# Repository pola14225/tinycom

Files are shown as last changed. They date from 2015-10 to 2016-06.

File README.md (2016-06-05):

# TinyCom

A small and low cost modular computer system.

Features:
- dimensions less than 5x5cm
- single, dual or quad core 1GHz CPU
- 512GB or 1GB RAM
- USB, HDMI, WIFI, Bluetooth, SD-card, camera, microphones
- real-time clock with battery, on-board temperature sensor
- **made only from widely available parts**
- **can reliably be assembled at home with DIY tools**

Modules:
- TinyCom-A13
- [TinyCom-A20](#tinycom-a20)
- TinyCom-A64
- TinyCom-USB
- [TinyCom-HDMI](#tinycom-hdmi)
- TinyCom-Pilot

## TinyCom-A20

### Specifications

- Dimensions: 4x4 cm
- CPU: Allwinner A20 (Dual-Core ARM Cortex-A7 @ 1Ghz, 40nm process)
- Memory: 512MB DDR3 SDRAM
- PCB: 4 layers, 6 mil traces, 12 mil vias
- Ports: SD-card, serial, USBx3, HDMI, camera

### Pictures

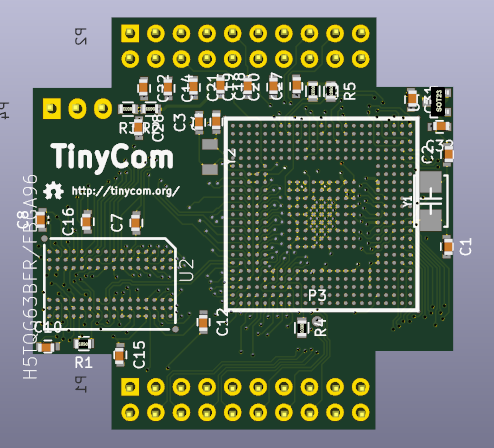
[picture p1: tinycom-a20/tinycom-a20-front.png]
TinyCom-A20 Front


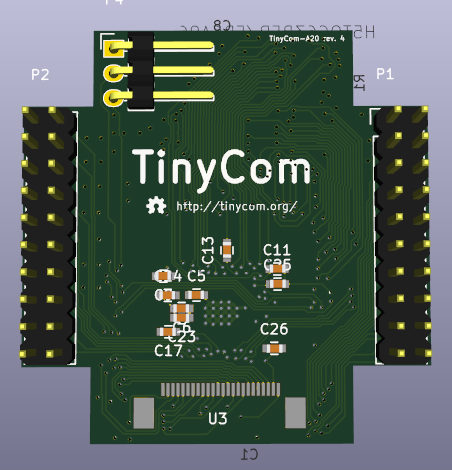
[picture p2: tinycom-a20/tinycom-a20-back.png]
TinyCom-A20 Back


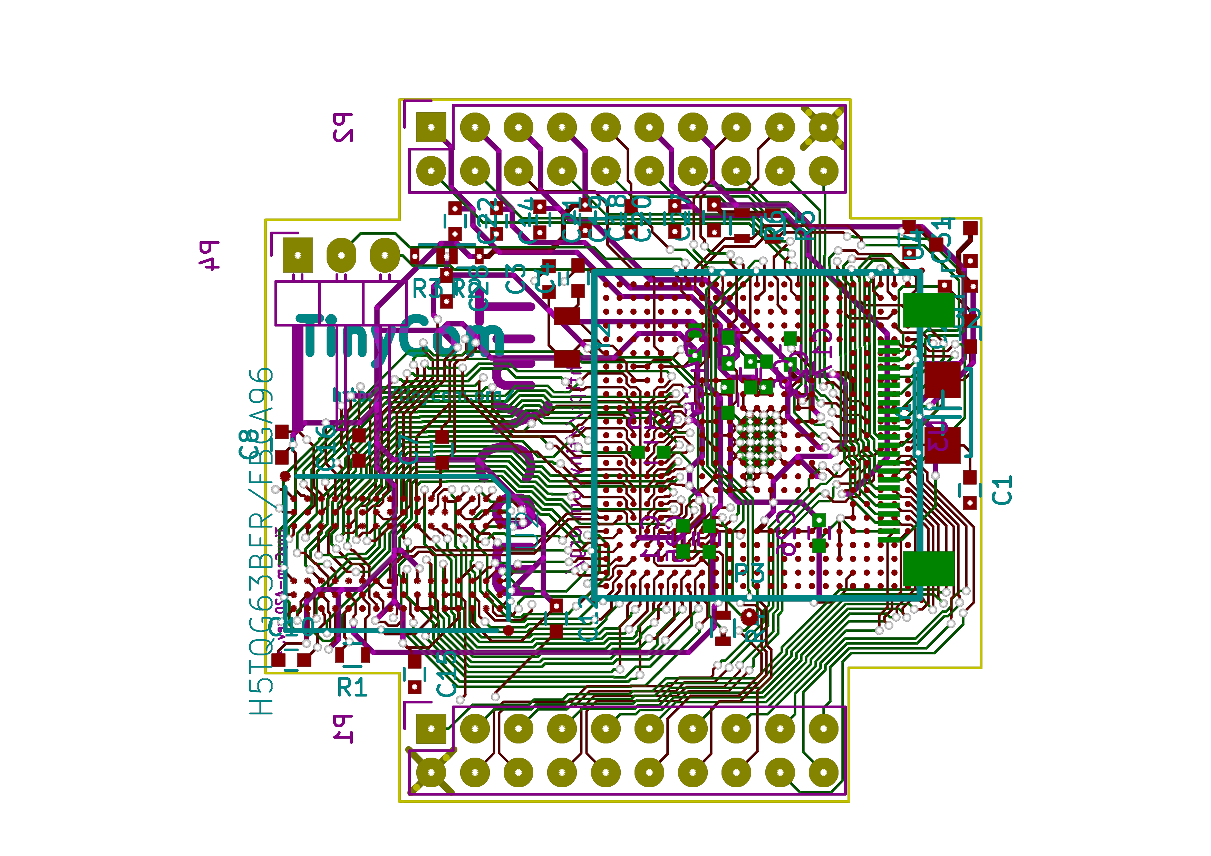
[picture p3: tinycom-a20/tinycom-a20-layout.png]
TinyCom-A20 Layout


## TinyCom-HDMI

- Connectors:  SD-card, USB, HDMI
- Network: WIFI, Bluetooth, ceramic antenna
- 2 microphones
- RTC backup battery
- Board temperature sensor
- PCB: 2 layers

### Pictures

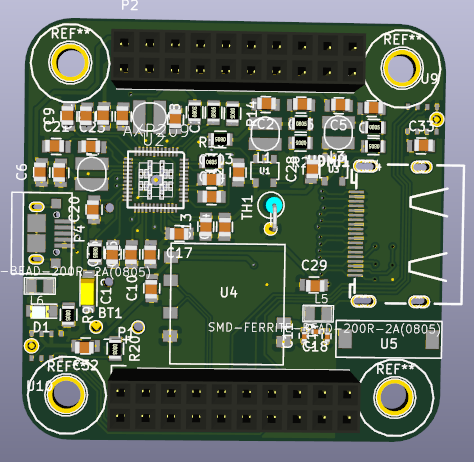
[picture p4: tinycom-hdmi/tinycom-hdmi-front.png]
TinyCom-HDMI Front


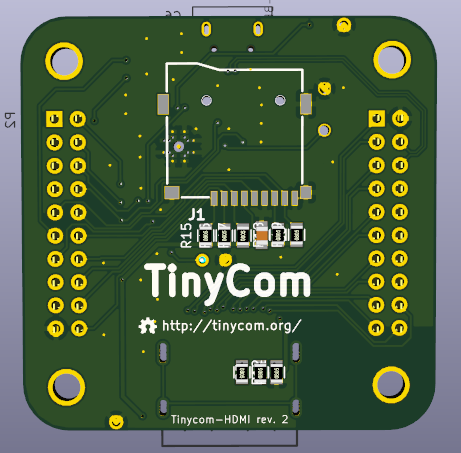
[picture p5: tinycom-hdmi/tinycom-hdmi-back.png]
TinyCom-HDMI Back


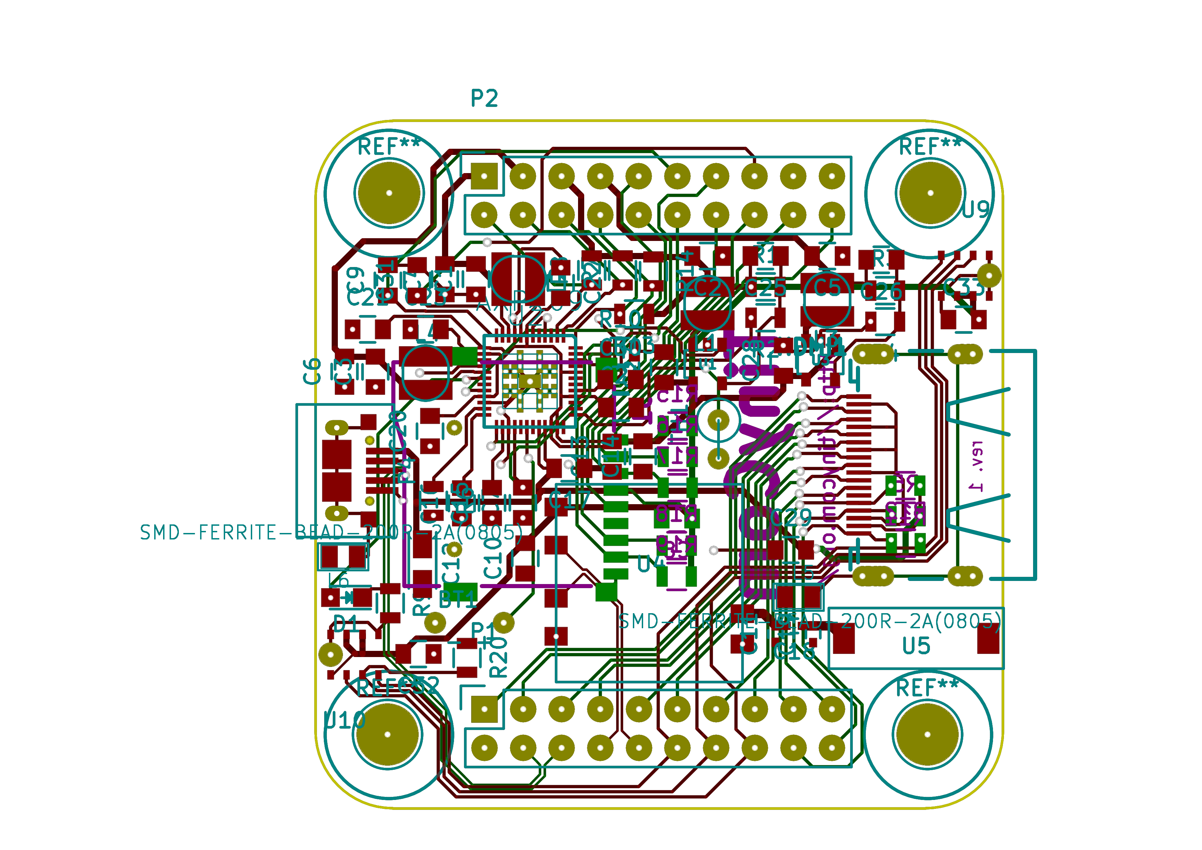
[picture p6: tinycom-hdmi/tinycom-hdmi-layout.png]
TinyCom-HDMI Layout


## Contact

Send email to dj@netforce.com.

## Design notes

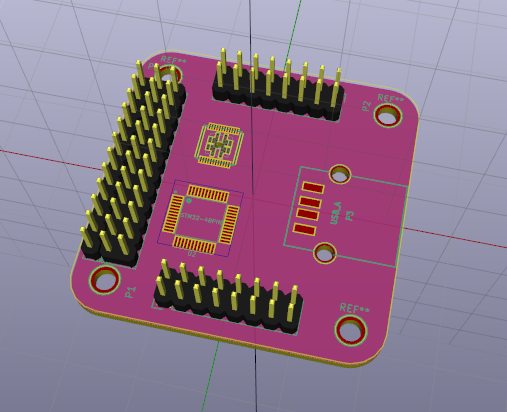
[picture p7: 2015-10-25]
tinycom-pilot/tinycom-pwm-3d.png

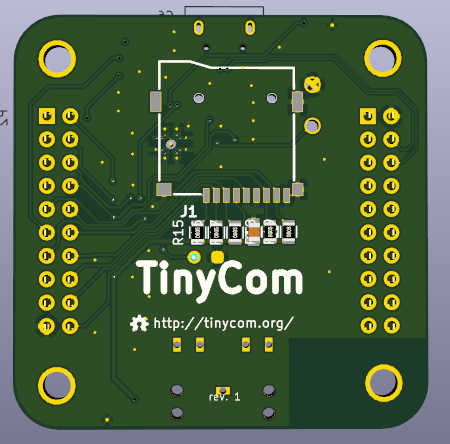
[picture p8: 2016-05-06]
tinycom-audio/tinycom-audio-back.png

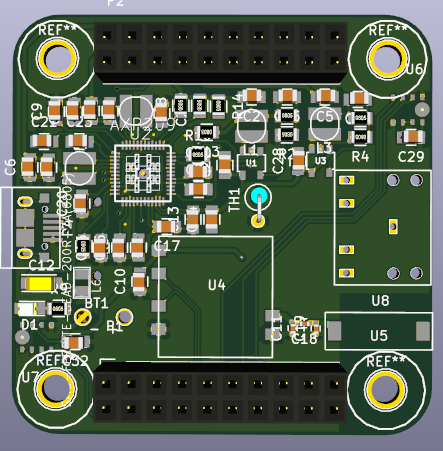
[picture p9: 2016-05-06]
tinycom-audio/tinycom-audio-front.png

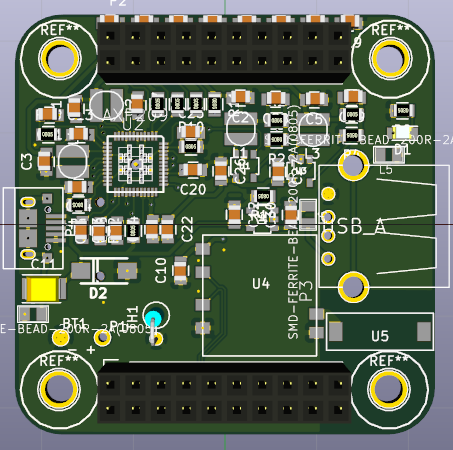
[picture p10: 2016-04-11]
tinycom-usb/tinycom-usb-front.png

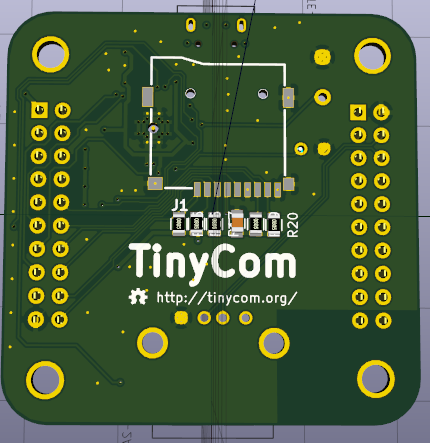
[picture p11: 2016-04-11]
tinycom-usb/tinycom-usb-back.png

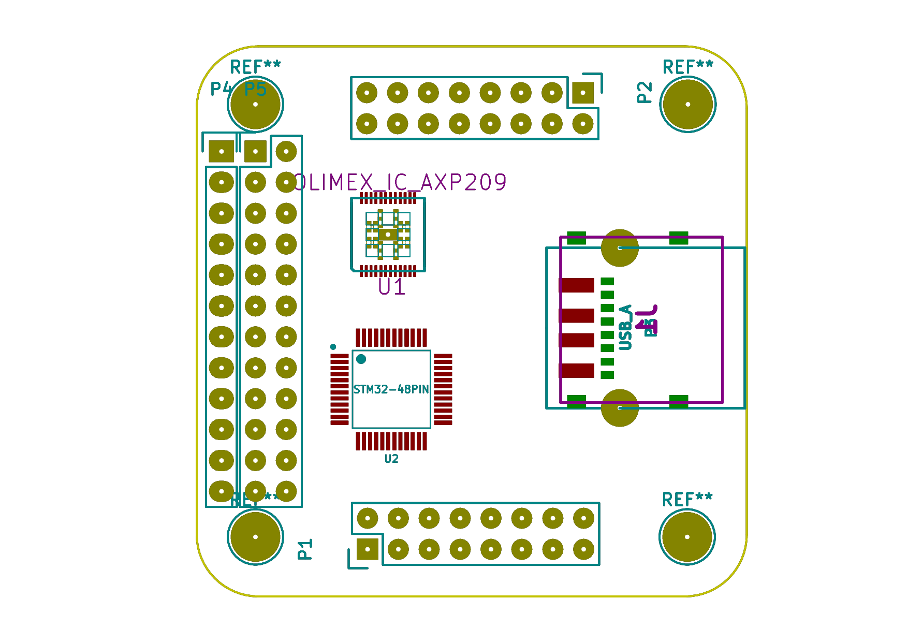
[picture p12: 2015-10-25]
tinycom-pilot/tinycom-pwm-board.png

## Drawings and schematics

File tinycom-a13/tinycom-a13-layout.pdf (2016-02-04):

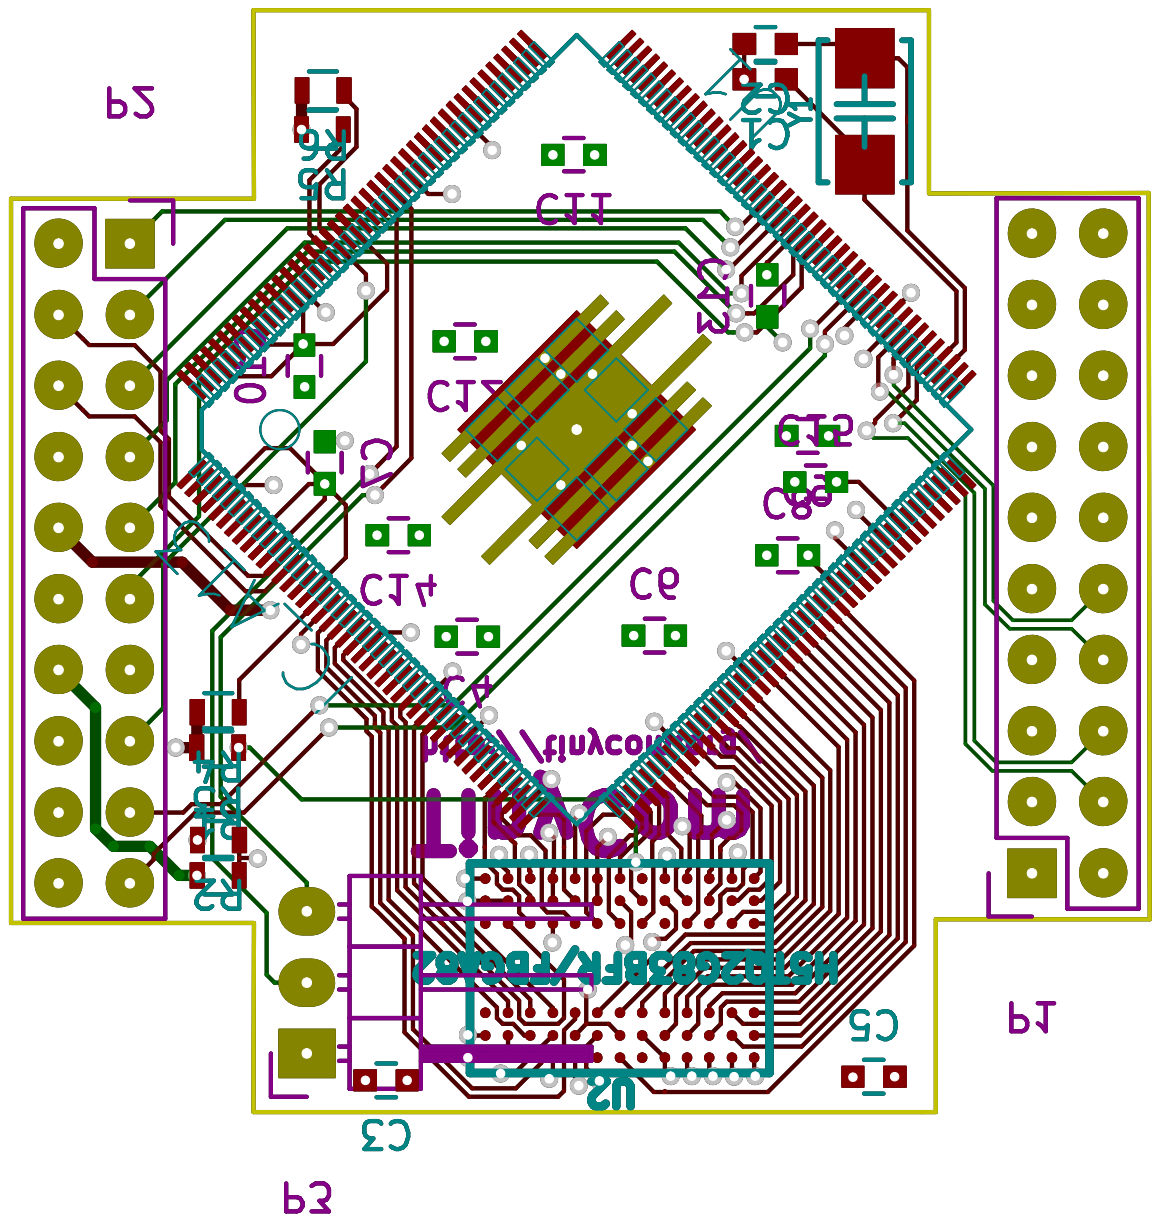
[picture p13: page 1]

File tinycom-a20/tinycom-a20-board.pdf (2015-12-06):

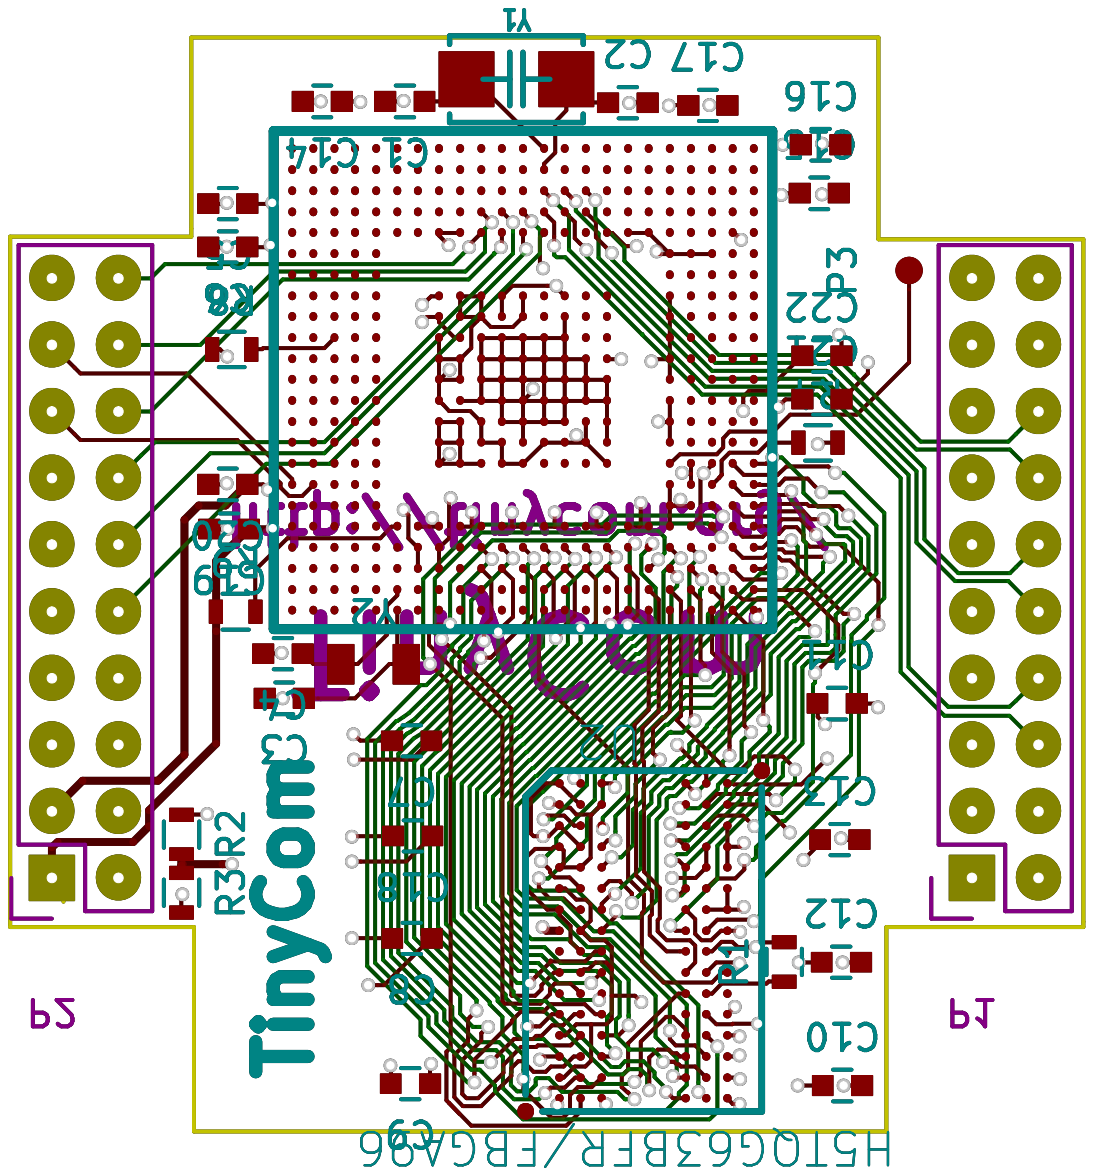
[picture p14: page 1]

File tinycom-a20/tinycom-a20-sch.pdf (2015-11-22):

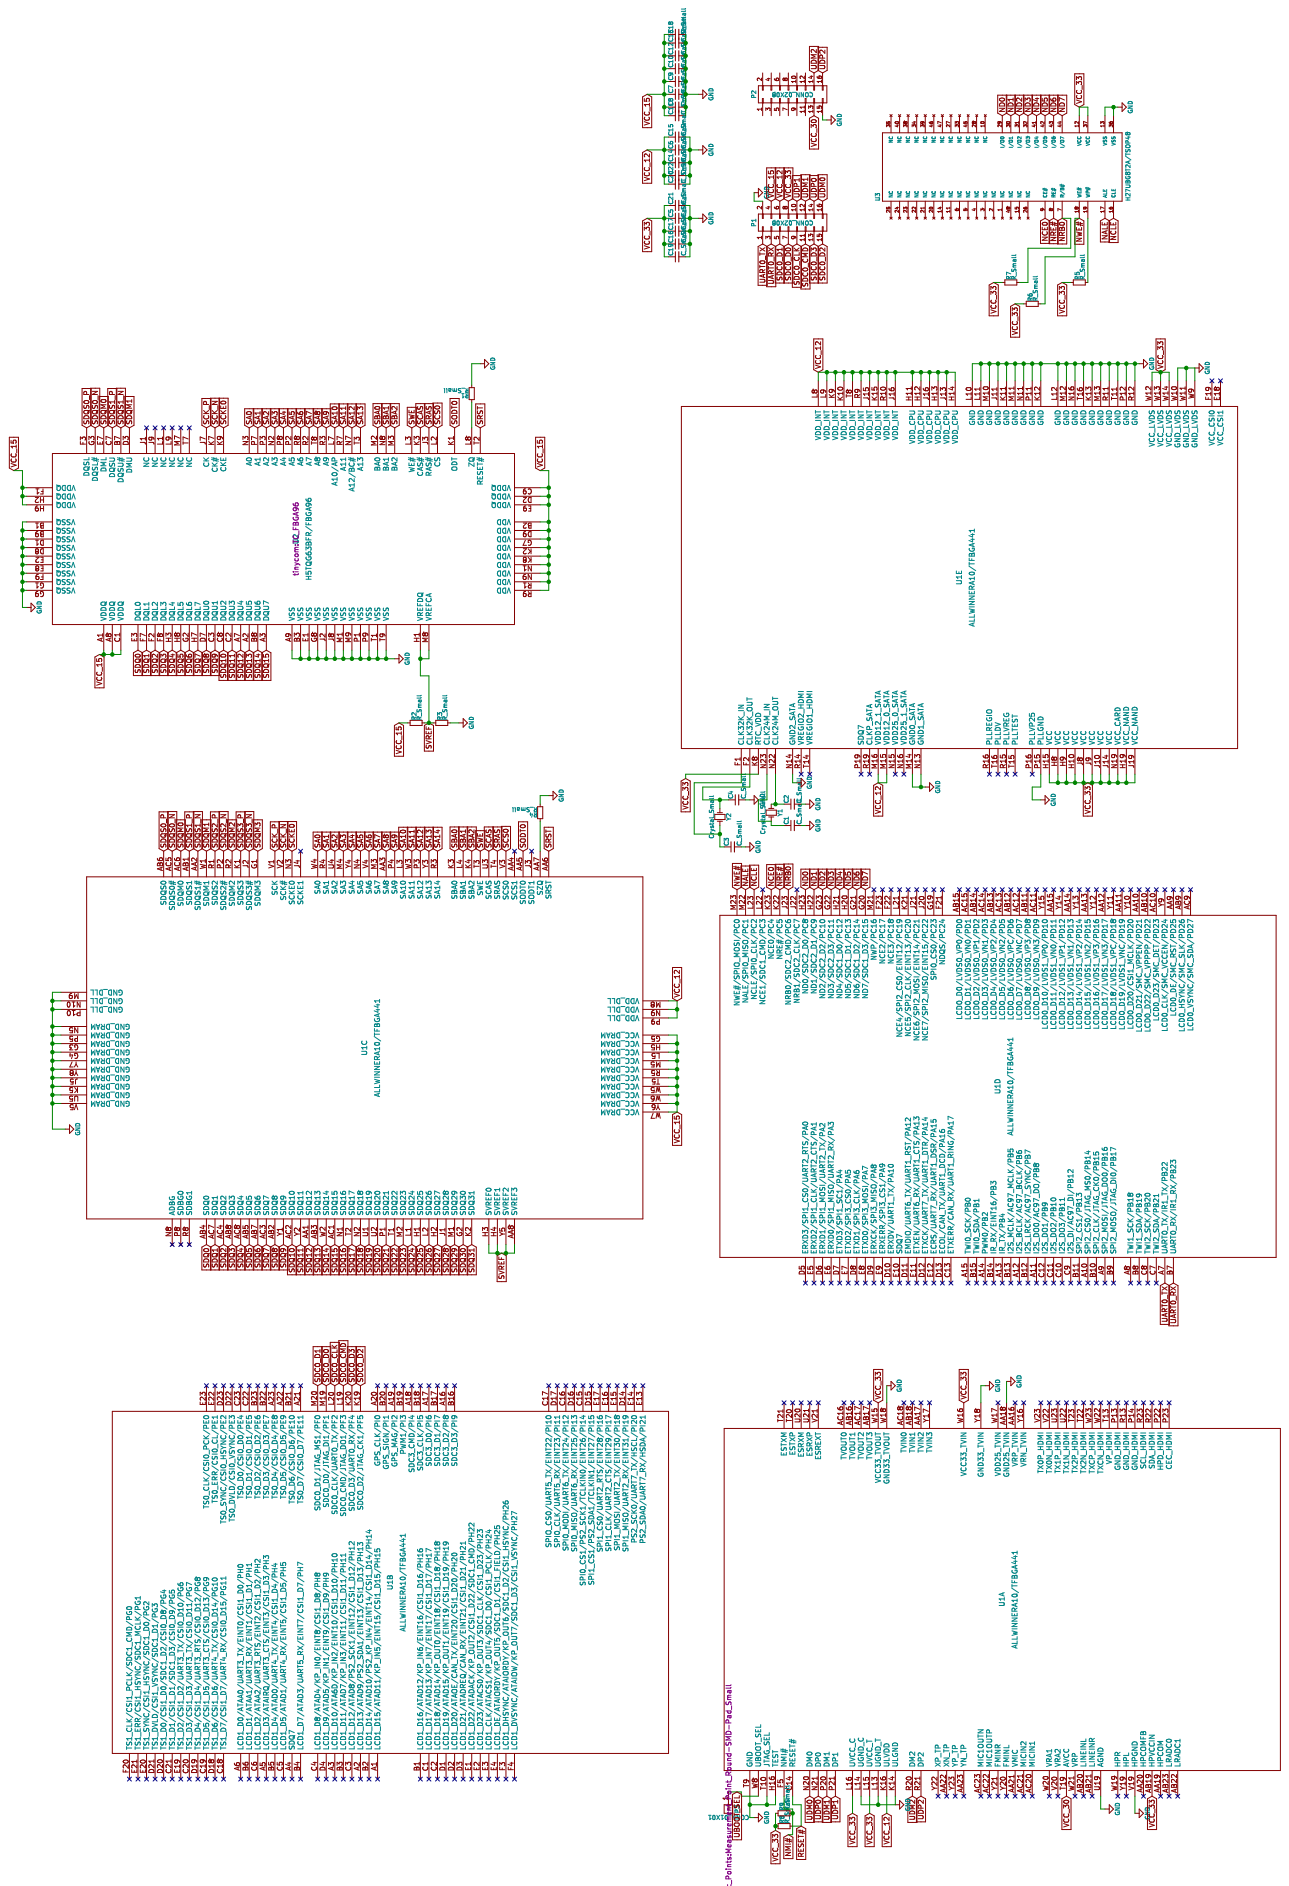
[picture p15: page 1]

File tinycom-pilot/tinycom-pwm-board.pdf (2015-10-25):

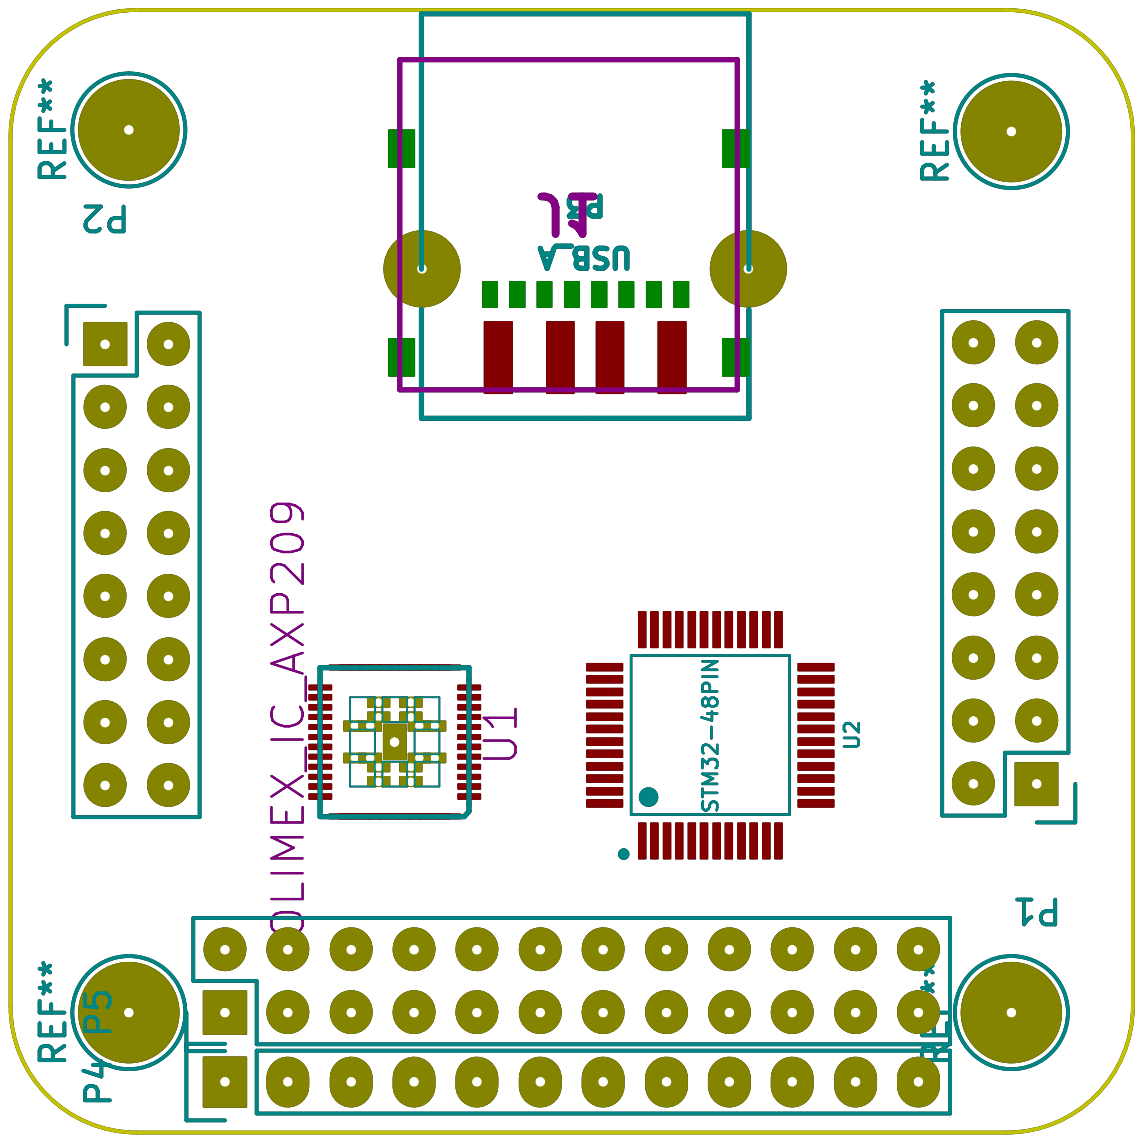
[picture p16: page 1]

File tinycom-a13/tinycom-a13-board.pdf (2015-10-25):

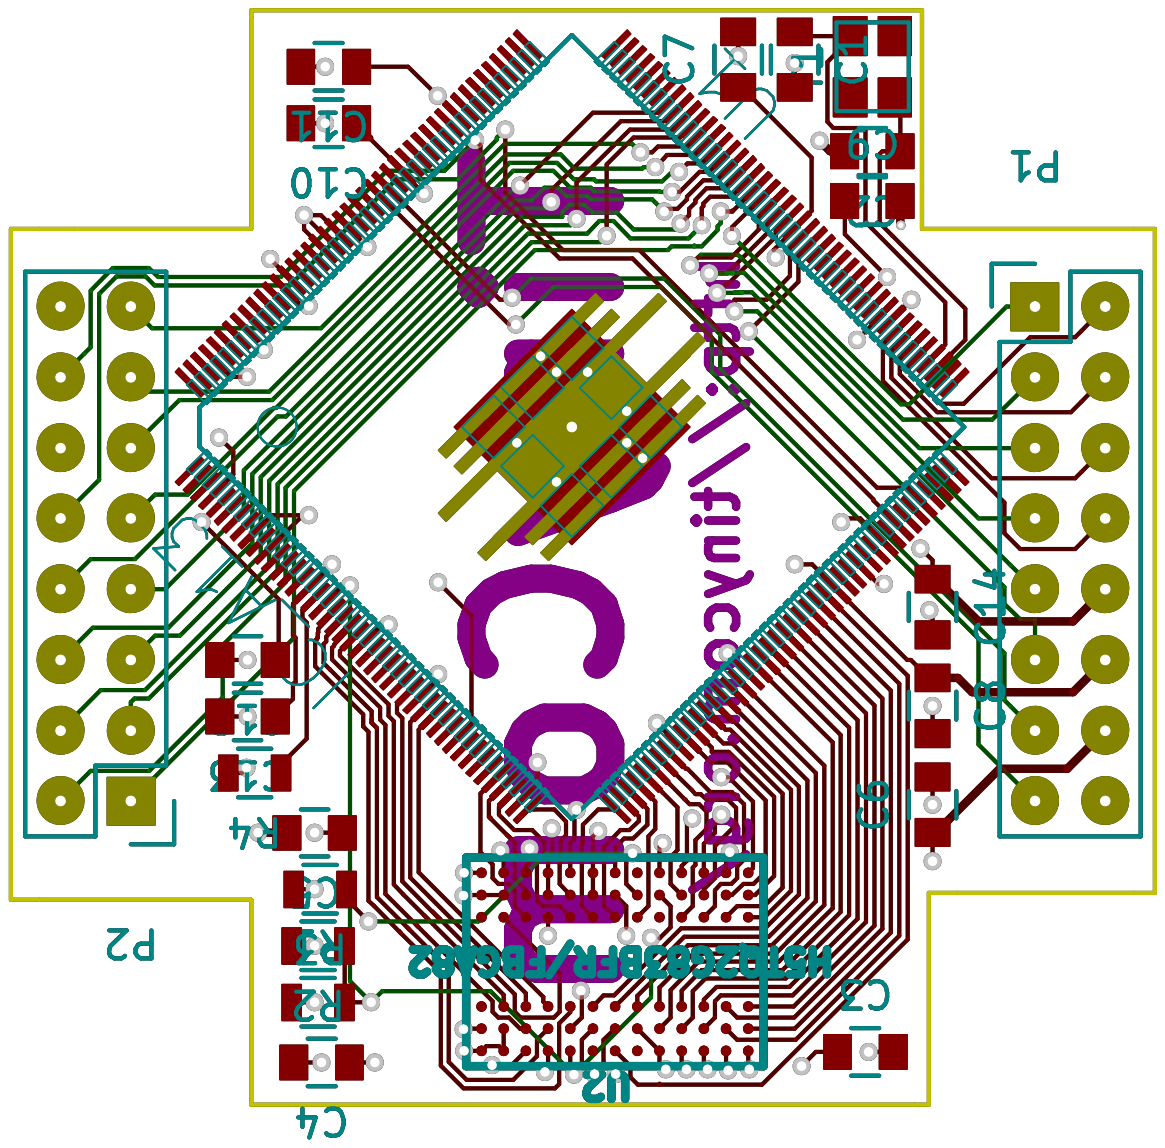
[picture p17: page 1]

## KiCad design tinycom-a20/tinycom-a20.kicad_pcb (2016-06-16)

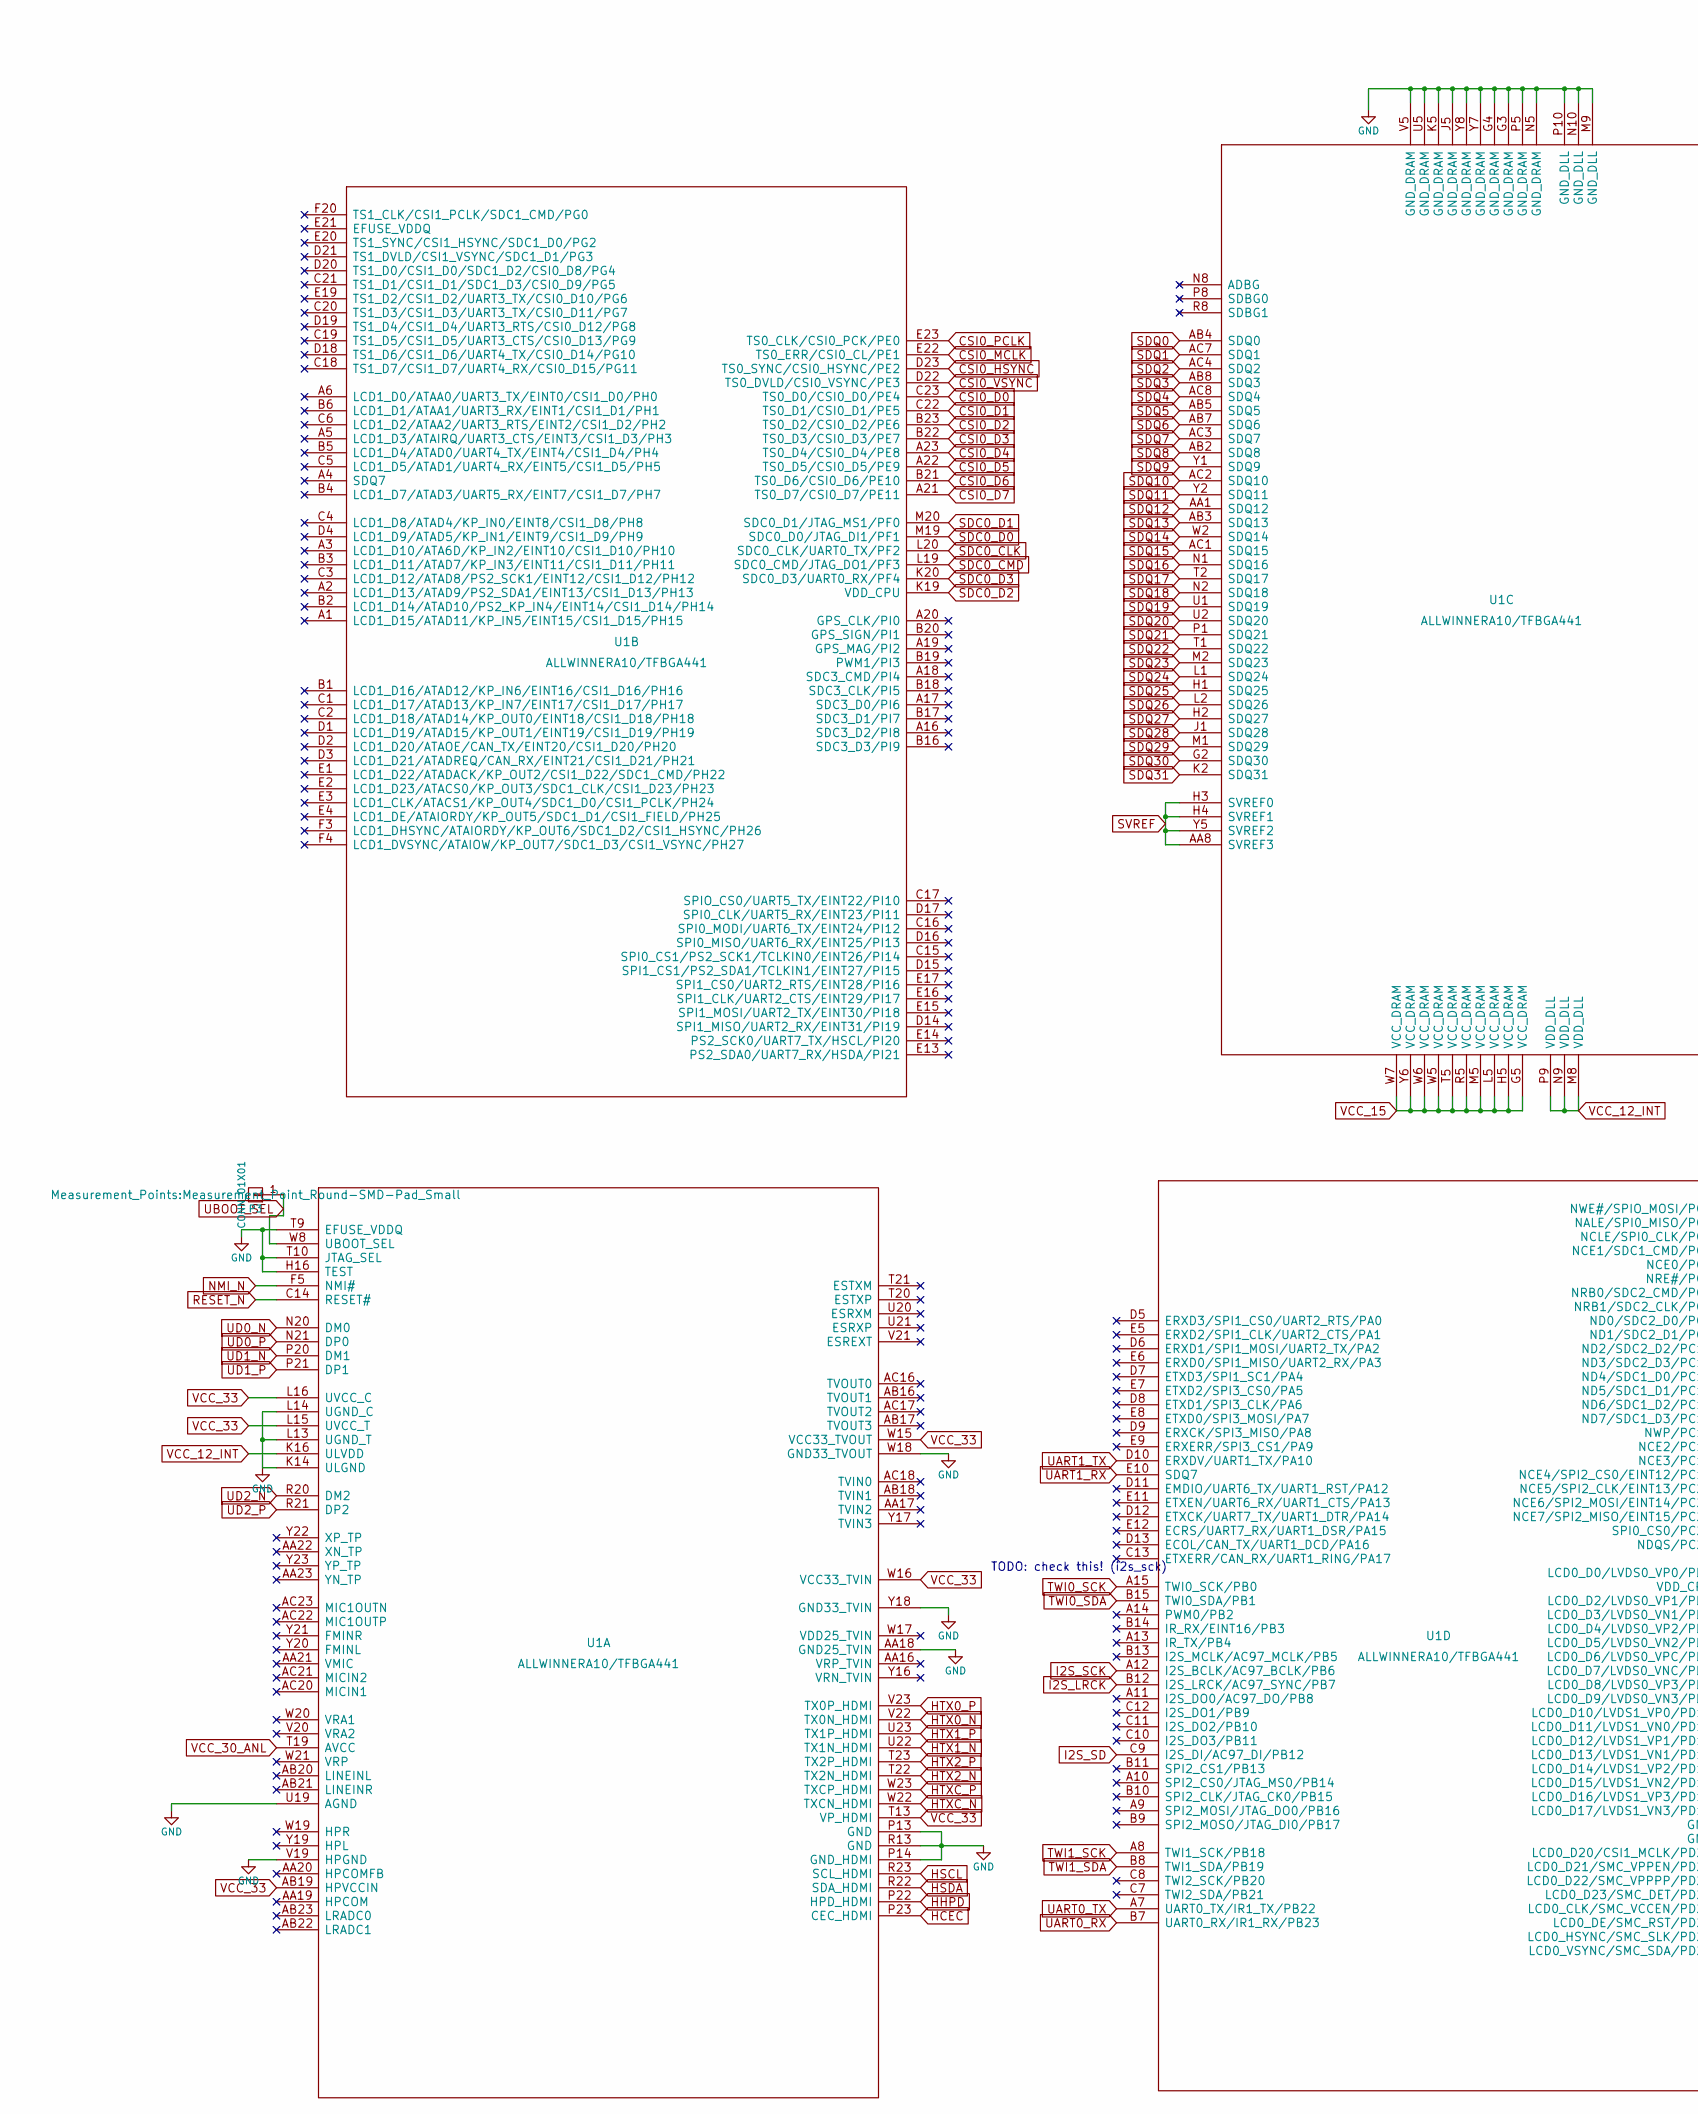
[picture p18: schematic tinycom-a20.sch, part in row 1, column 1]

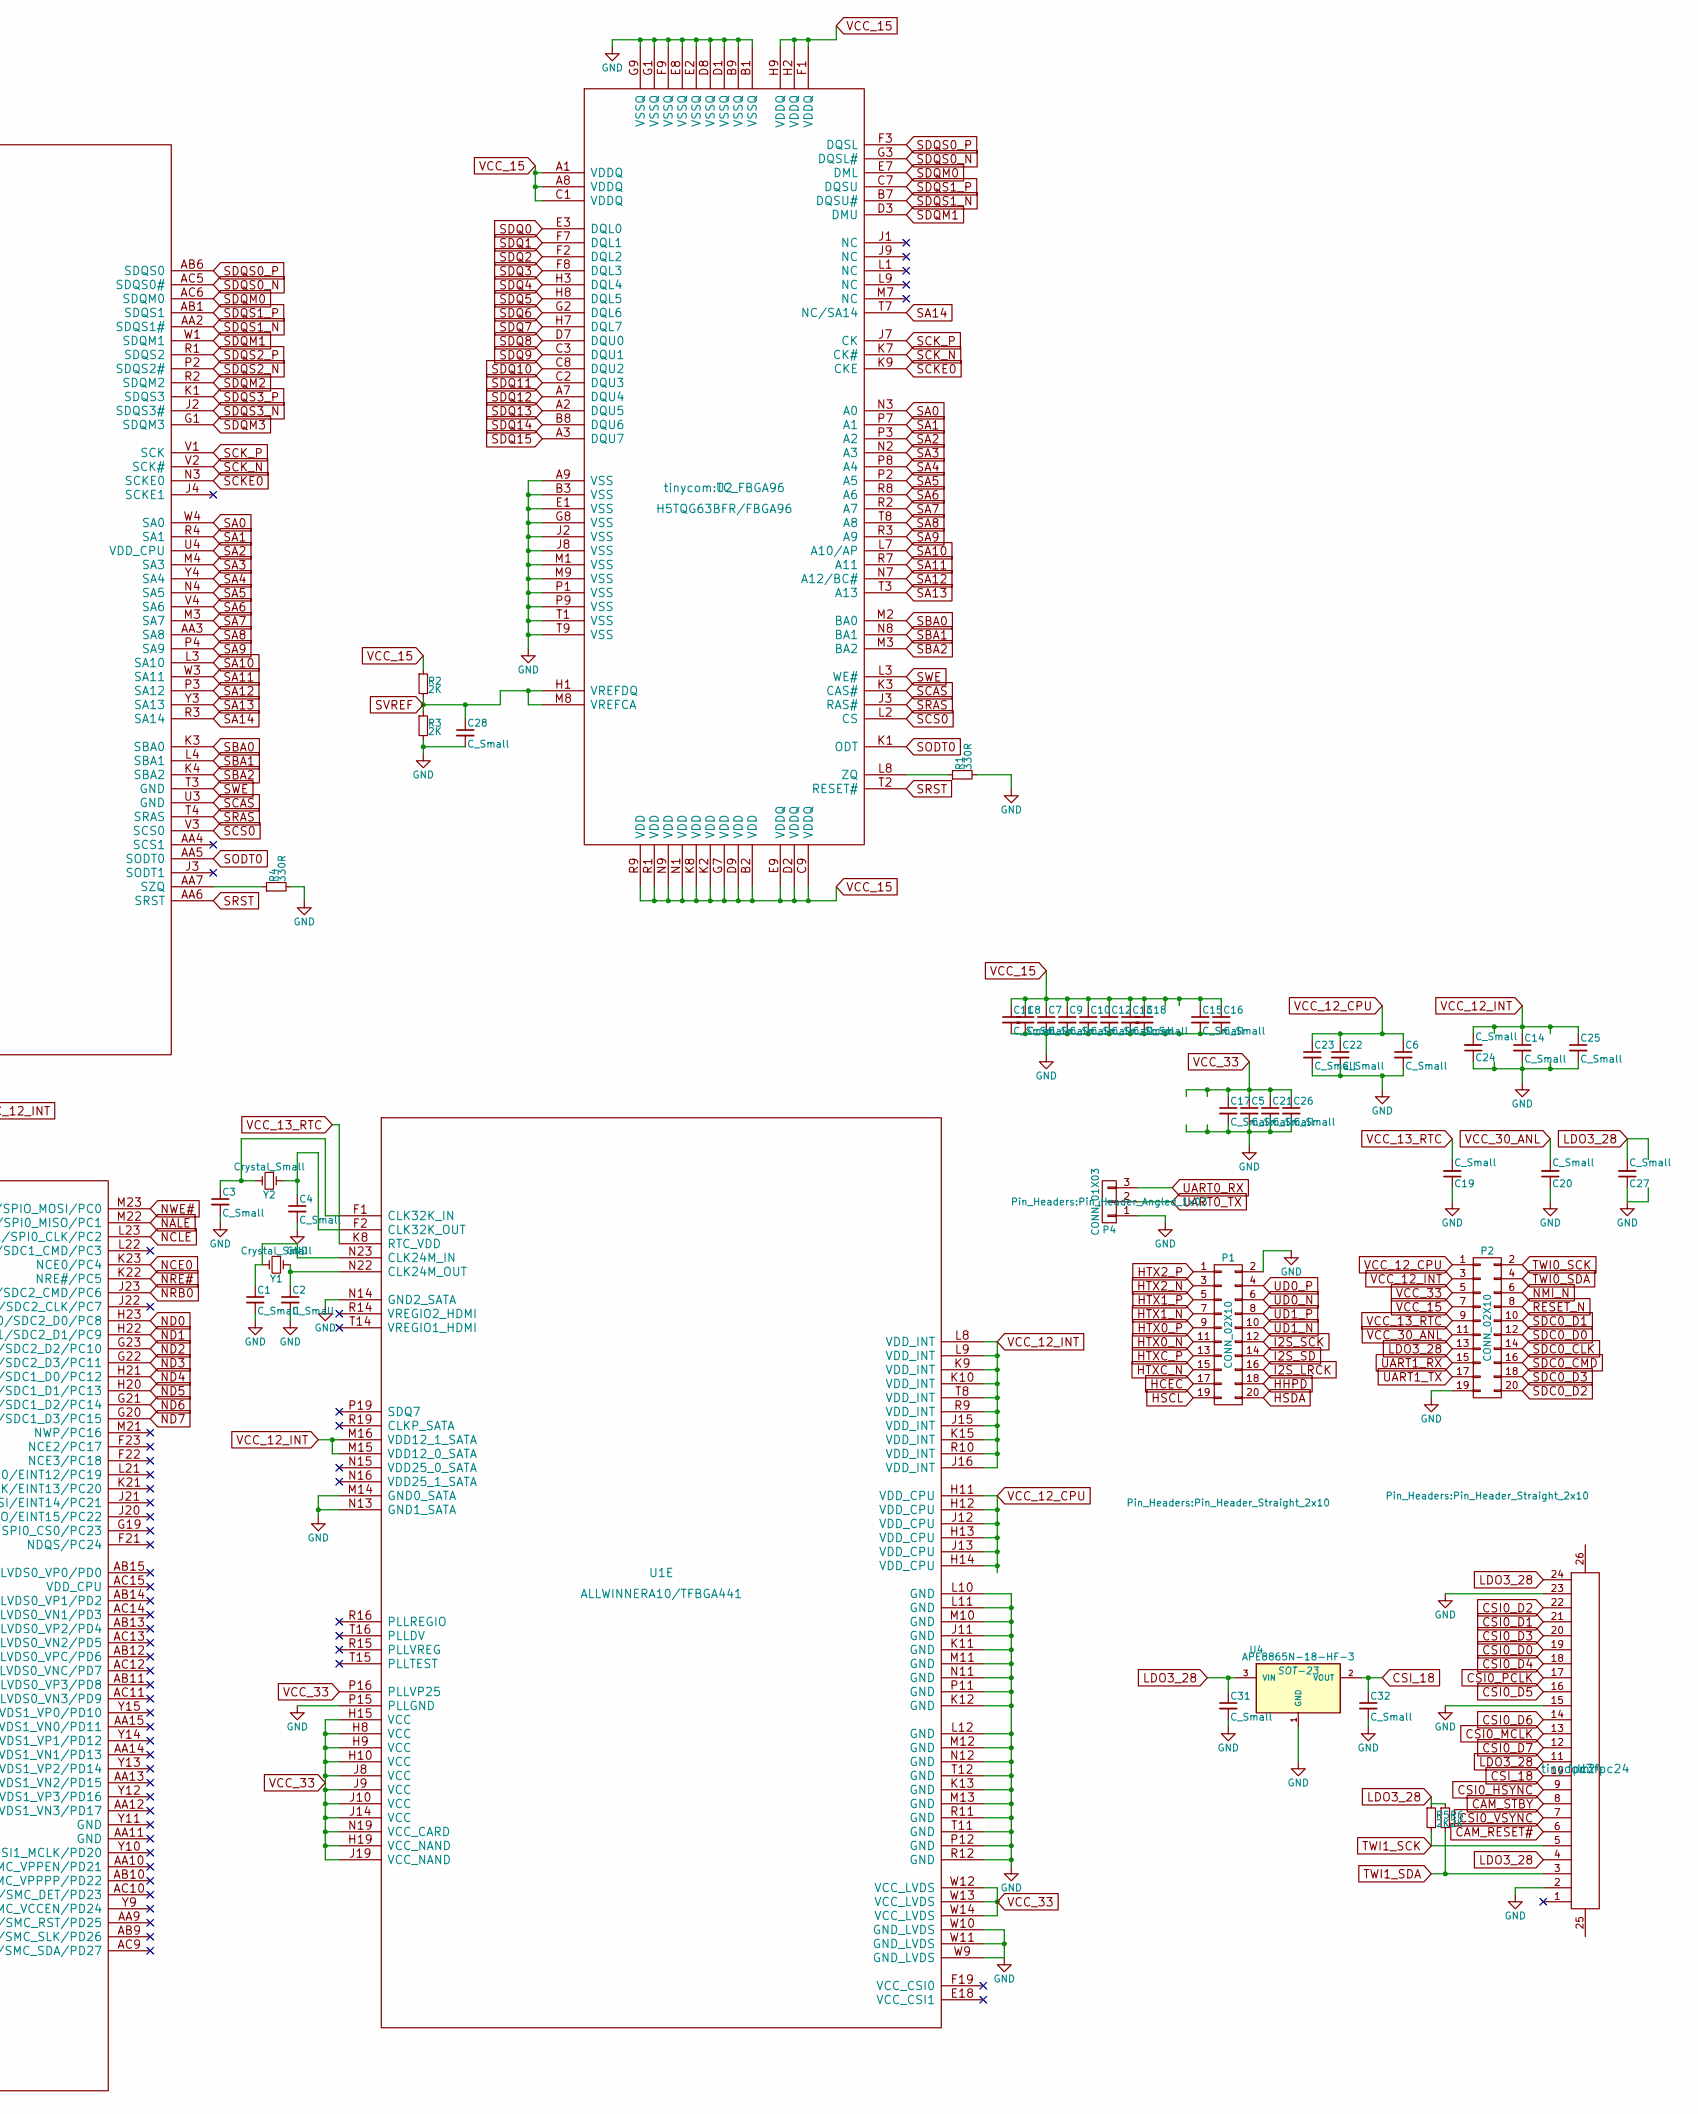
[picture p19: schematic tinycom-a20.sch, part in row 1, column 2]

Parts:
C1, C2, C3, C4, C5, C6, C7, C8, C9, C10, C11, C12, C13, C14, C15, C16, C17, C18, C19, C20, C21, C22, C23, C24, C25, C26, C27, C28, C31, C32: C_Small; C_0603
P1, P2: CONN_02X10; Pin_Header_Straight_2x10
P3: CONN_01X01; Measurement_Point_Round-SMD-Pad_Small
P4: CONN_01X03; Pin_Header_Angled_1x03
R1, R4: 330R; R_0603
R2, R3, R5, R6: 2K; R_0603
U1: ALLWINNERA10/TFBGA441; 441TFBGA-P0.8
U2: H5TQG63BFR/FBGA96; TC_FBGA96
U3: fpc24
U4: APE8865N-18-HF-3; SOT-23
Y1: Crystal_Small; Crystal_5x3.2mm
Y2: Crystal_Small; crystal3215

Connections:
CAM_RESET#: U3.6
CAM_STBY: U3.8
CSI0_D0: U1.C23 (TS0_D0/CSI0_D0/PE4), U3.19
CSI0_D1: U1.C22 (TS0_D1/CSI0_D1/PE5), U3.21
CSI0_D2: U1.B23 (TS0_D2/CSI0_D2/PE6), U3.22
CSI0_D3: U1.B22 (TS0_D3/CSI0_D3/PE7), U3.20
CSI0_D4: U1.A23 (TS0_D4/CSI0_D4/PE8), U3.18
CSI0_D5: U1.A22 (TS0_D5/CSI0_D5/PE9), U3.16
CSI0_D6: U1.B21 (TS0_D6/CSI0_D6/PE10), U3.14
CSI0_D7: U1.A21 (TS0_D7/CSI0_D7/PE11), U3.12
CSI0_HSYNC: U1.D23 (TS0_SYNC/CSI0_HSYNC/PE2), U3.9
CSI0_MCLK: U1.E22 (TS0_ERR/CSI0_CL/PE1), U3.13
CSI0_PCLK: U1.E23 (TS0_CLK/CSI0_PCK/PE0), U3.17
CSI0_VSYNC: U1.D22 (TS0_DVLD/CSI0_VSYNC/PE3), U3.7
CSI_18: C32.1, U3.10, U4.2 (VOUT)
GND: C1.2, C2.2, C3.2, C4.2, C5.2, C6.2, C7.2, C8.2, C9.2, C10.2, C11.2, C12.2, C13.2, C14.2, C15.2, C16.2, C17.2, C18.2, C19.1, C20.1, C21.2, C22.2, C23.2, C24.1, C25.2, C26.2, C27.1, C28.2, C31.2, C32.2, P1.2, P2.19, P4.1, R1.2, R3.2, R4.2, U1.AA18 (GND25_TVIN), U1.G3 (GND_DRAM), U1.G4 (GND_DRAM), U1.H16 (TEST), U1.J5 (GND_DRAM), U1.J11 (GND), U1.K5 (GND_DRAM), U1.K11 (GND), U1.K12 (GND), U1.K13 (GND), U1.K14 (ULGND), U1.L10 (GND), U1.L11 (GND), U1.L12 (GND), U1.L13 (UGND_T), U1.L14 (UGND_C), U1.M9 (GND_DLL), U1.M10 (GND), U1.M11 (GND), U1.M12 (GND), U1.M13 (GND), U1.M14 (GND0_SATA), U1.N5 (GND_DRAM), U1.N10 (GND_DLL), U1.N11 (GND), U1.N12 (GND), U1.N13 (GND1_SATA), U1.N14 (GND2_SATA), U1.P5 (GND_DRAM), U1.P10 (GND_DLL), U1.P11 (GND), U1.P12 (GND), U1.P13 (GND), U1.P14 (GND_HDMI), U1.P15 (PLLGND), U1.R11 (GND), U1.R12 (GND), U1.R13 (GND), U1.T9 (EFUSE_VDDQ), U1.T10 (JTAG_SEL), U1.T11 (GND), U1.T12 (GND), U1.U5 (GND_DRAM), U1.U19 (AGND), U1.V5 (GND_DRAM), U1.V19 (HPGND), U1.W9 (GND_LVDS), U1.W10 (GND_LVDS), U1.W11 (GND_LVDS), U1.W18 (GND33_TVOUT), U1.Y7 (GND_DRAM), U1.Y8 (GND_DRAM), U1.Y18 (GND33_TVIN), U2.A9 (VSS), U2.B1 (VSSQ), U2.B3 (VSS), U2.B9 (VSSQ), U2.D1 (VSSQ), U2.D8 (VSSQ), U2.E1 (VSS), U2.E2 (VSSQ), U2.E8 (VSSQ), U2.F9 (VSSQ), U2.G1 (VSSQ), U2.G8 (VSS), U2.G9 (VSSQ), U2.J2 (VSS), U2.J8 (VSS), U2.M1 (VSS), U2.M9 (VSS), U2.P1 (VSS), U2.P9 (VSS), U2.T1 (VSS), U2.T9 (VSS), U3.2, U3.15, U3.23, U4.1 (GND)
HCEC: P1.17, U1.P23 (CEC_HDMI)
HHPD: P1.18, U1.P22 (HPD_HDMI)
HSCL: P1.19, U1.R23 (SCL_HDMI)
HSDA: P1.20, U1.R22 (SDA_HDMI)
HTX0_N: P1.11, U1.V22 (TX0N_HDMI)
HTX0_P: P1.9, U1.V23 (TX0P_HDMI)
HTX1_N: P1.7, U1.U22 (TX1N_HDMI)
HTX1_P: P1.5, U1.U23 (TX1P_HDMI)
HTX2_N: P1.3, U1.T22 (TX2N_HDMI)
HTX2_P: P1.1, U1.T23 (TX2P_HDMI)
HTXC_N: P1.15, U1.W22 (TXCN_HDMI)
HTXC_P: P1.13, U1.W23 (TXCP_HDMI)
I2S_LRCK: P1.16, U1.B12 (I2S_LRCK/AC97_SYNC/PB7)
I2S_SCK: P1.12, U1.A12 (I2S_BCLK/AC97_BCLK/PB6)
I2S_SD: P1.14, U1.C9 (I2S_DI/AC97_DI/PB12)
LDO3_28: C27.2, C31.1, P2.13, R5.1, R6.1, U3.4, U3.11, U3.24, U4.3 (VIN)
NALE: U1.M22 (NALE/SPI0_MISO/PC1)
NCE0: U1.K23 (NCE0/PC4)
NCLE: U1.L23 (NCLE/SPI0_CLK/PC2)
ND0: U1.H23 (ND0/SDC2_D0/PC8)
ND1: U1.H22 (ND1/SDC2_D1/PC9)
ND2: U1.G23 (ND2/SDC2_D2/PC10)
ND3: U1.G22 (ND3/SDC2_D3/PC11)
ND4: U1.H21 (ND4/SDC1_D0/PC12)
ND5: U1.H20 (ND5/SDC1_D1/PC13)
ND6: U1.G21 (ND6/SDC1_D2/PC14)
ND7: U1.G20 (ND7/SDC1_D3/PC15)
NMI_N: P2.6, U1.F5 (NMI#)
NRB0: U1.J23 (NRB0/SDC2_CMD/PC6)
NRE#: U1.K22 (NRE#/PC5)
NWE#: U1.M23 (NWE#/SPIO_MOSI/PC0)
unnamed: C1.1, U1.N23 (CLK24M_IN), Y1.2
unnamed: C2.1, U1.N22 (CLK24M_OUT), Y1.1
unnamed: C3.1, U1.F1 (CLK32K_IN), Y2.2
unnamed: C4.1, U1.F2 (CLK32K_OUT), Y2.1
unnamed: R1.1, U2.L8 (ZQ)
unnamed: R4.1, U1.AA7 (SZQ)
RESET_N: P2.8, U1.C14 (RESET#)
SA0: U1.W4 (SA0), U2.N3 (A0)
SA1: U1.R4 (SA1), U2.P7 (A1)
SA2: U1.U4 (VDD_CPU), U2.P3 (A2)
SA3: U1.M4 (SA3), U2.N2 (A3)
SA4: U1.Y4 (SA4), U2.P8 (A4)
SA5: U1.N4 (SA5), U2.P2 (A5)
SA6: U1.V4 (SA6), U2.R8 (A6)
SA7: U1.M3 (SA7), U2.R2 (A7)
SA8: U1.AA3 (SA8), U2.T8 (A8)
SA9: U1.P4 (SA9), U2.R3 (A9)
SA10: U1.L3 (SA10), U2.L7 (A10/AP)
SA11: U1.W3 (SA11), U2.R7 (A11)
SA12: U1.P3 (SA12), U2.N7 (A12/BC#)
SA13: U1.Y3 (SA13), U2.T3 (A13)
SA14: U1.R3 (SA14), U2.T7 (NC/SA14)
SBA0: U1.K3 (SBA0), U2.M2 (BA0)
SBA1: U1.L4 (SBA1), U2.N8 (BA1)
SBA2: U1.K4 (SBA2), U2.M3 (BA2)
SCAS: U1.U3 (GND), U2.K3 (CAS#)
SCKE0: U1.N3 (SCKE0), U2.K9 (CKE)
SCK_N: U1.V2 (SCK#), U2.K7 (CK#)
SCK_P: U1.V1 (SCK), U2.J7 (CK)
SCS0: U1.V3 (SCS0), U2.L2 (CS)
SDC0_CLK: P2.14, U1.L20 (SDC0_CLK/UART0_TX/PF2)
SDC0_CMD: P2.16, U1.L19 (SDC0_CMD/JTAG_DO1/PF3)
SDC0_D0: P2.12, U1.M19 (SDC0_D0/JTAG_DI1/PF1)
SDC0_D1: P2.10, U1.M20 (SDC0_D1/JTAG_MS1/PF0)
SDC0_D2: P2.20, U1.K19 (VDD_CPU)
SDC0_D3: P2.18, U1.K20 (SDC0_D3/UART0_RX/PF4)
SDQ0: U1.AB4 (SDQ0), U2.E3 (DQL0)
SDQ1: U1.AC7 (SDQ1), U2.F7 (DQL1)
SDQ2: U1.AC4 (SDQ2), U2.F2 (DQL2)
SDQ3: U1.AB8 (SDQ3), U2.F8 (DQL3)
SDQ4: U1.AC8 (SDQ4), U2.H3 (DQL4)
SDQ5: U1.AB5 (SDQ5), U2.H8 (DQL5)
SDQ6: U1.AB7 (SDQ6), U2.G2 (DQL6)
SDQ7: U1.AC3 (SDQ7), U2.H7 (DQL7)
SDQ8: U1.AB2 (SDQ8), U2.D7 (DQU0)
SDQ9: U1.Y1 (SDQ9), U2.C3 (DQU1)
SDQ10: U1.AC2 (SDQ10), U2.C8 (DQU2)
SDQ11: U1.Y2 (SDQ11), U2.C2 (DQU3)
SDQ12: U1.AA1 (SDQ12), U2.A7 (DQU4)
SDQ13: U1.AB3 (SDQ13), U2.A2 (DQU5)
SDQ14: U1.W2 (SDQ14), U2.B8 (DQU6)
SDQ15: U1.AC1 (SDQ15), U2.A3 (DQU7)
SDQ16: U1.N1 (SDQ16)
SDQ17: U1.T2 (SDQ17)
SDQ18: U1.N2 (SDQ18)
SDQ19: U1.U1 (SDQ19)
SDQ20: U1.U2 (SDQ20)
SDQ21: U1.P1 (SDQ21)
SDQ22: U1.T1 (SDQ22)
SDQ23: U1.M2 (SDQ23)
SDQ24: U1.L1 (SDQ24)
SDQ25: U1.H1 (SDQ25)
SDQ26: U1.L2 (SDQ26)
SDQ27: U1.H2 (SDQ27)
SDQ28: U1.J1 (SDQ28)
SDQ29: U1.M1 (SDQ29)
SDQ30: U1.G2 (SDQ30)
SDQ31: U1.K2 (SDQ31)
SDQM0: U1.AC6 (SDQM0), U2.E7 (DML)
SDQM1: U1.W1 (SDQM1), U2.D3 (DMU)
SDQM2: U1.R2 (SDQM2)
SDQM3: U1.G1 (SDQM3)
SDQS0_N: U1.AC5 (SDQS0#), U2.G3 (DQSL#)
SDQS0_P: U1.AB6 (SDQS0), U2.F3 (DQSL)
SDQS1_N: U1.AA2 (SDQS1#), U2.B7 (DQSU#)
SDQS1_P: U1.AB1 (SDQS1), U2.C7 (DQSU)
SDQS2_N: U1.P2 (SDQS2#)
SDQS2_P: U1.R1 (SDQS2)
SDQS3_N: U1.J2 (SDQS3#)
SDQS3_P: U1.K1 (SDQS3)
SODT0: U1.AA5 (SODT0), U2.K1 (ODT)
SRAS: U1.T4 (SRAS), U2.J3 (RAS#)
SRST: U1.AA6 (SRST), U2.T2 (RESET#)
SVREF: C28.1, R2.2, R3.1, U1.AA8 (SVREF3), U1.H3 (SVREF0), U1.H4 (SVREF1), U1.Y5 (SVREF2), U2.H1 (VREFDQ), U2.M8 (VREFCA)
SWE: U1.T3 (GND), U2.L3 (WE#)
TWI0_SCK: P2.2, U1.A15 (TWI0_SCK/PB0)
TWI0_SDA: P2.4, U1.B15 (TWI0_SDA/PB1)
TWI1_SCK: R5.2, U1.A8 (TWI1_SCK/PB18), U3.5
TWI1_SDA: R6.2, U1.B8 (TWI1_SDA/PB19), U3.3
UART0_RX: P4.3, U1.B7 (UART0_RX/IR1_RX/PB23)
UART0_TX: P4.2, U1.A7 (UART0_TX/IR1_TX/PB22)
UART1_RX: P2.15, U1.E10 (SDQ7)
UART1_TX: P2.17, U1.D10 (ERXDV/UART1_TX/PA10)
UBOOT_SEL: P3.1, U1.W8 (UBOOT_SEL)
UD0_N: P1.6, U1.N20 (DM0)
UD0_P: P1.4, U1.N21 (DP0)
UD1_N: P1.10, U1.P20 (DM1)
UD1_P: P1.8, U1.P21 (DP1)
UD2_N: U1.R20 (DM2)
UD2_P: U1.R21 (DP2)
VCC_12_CPU: C6.1, C22.1, C23.1, P2.1, U1.H11 (VDD_CPU), U1.H12 (VDD_CPU), U1.H13 (VDD_CPU), U1.H14 (VDD_CPU), U1.J12 (VDD_CPU), U1.J13 (VDD_CPU)
VCC_12_INT: C14.1, C24.2, C25.1, P2.3, U1.J15 (VDD_INT), U1.J16 (VDD_INT), U1.K9 (VDD_INT), U1.K10 (VDD_INT), U1.K15 (VDD_INT), U1.K16 (ULVDD), U1.L8 (VDD_INT), U1.L9 (VDD_INT), U1.M8 (VDD_DLL), U1.M15 (VDD12_0_SATA), U1.M16 (VDD12_1_SATA), U1.N9 (VDD_DLL), U1.P9 (VDD_DLL), U1.R9 (VDD_INT), U1.R10 (VDD_INT), U1.T8 (VDD_INT)
VCC_13_RTC: C19.2, P2.9, U1.K8 (RTC_VDD)
VCC_15: C7.1, C8.1, C9.1, C10.1, C11.1, C12.1, C13.1, C15.1, C16.1, C18.1, P2.7, R2.1, U1.G5 (VCC_DRAM), U1.H5 (VCC_DRAM), U1.L5 (VCC_DRAM), U1.M5 (VCC_DRAM), U1.R5 (VCC_DRAM), U1.T5 (VCC_DRAM), U1.W5 (VCC_DRAM), U1.W6 (VCC_DRAM), U1.W7 (VCC_DRAM), U1.Y6 (VCC_DRAM), U2.A1 (VDDQ), U2.A8 (VDDQ), U2.B2 (VDD), U2.C1 (VDDQ), U2.C9 (VDDQ), U2.D2 (VDDQ), U2.D9 (VDD), U2.E9 (VDDQ), U2.F1 (VDDQ), U2.G7 (VDD), U2.H2 (VDDQ), U2.H9 (VDDQ), U2.K2 (VDD), U2.K8 (VDD), U2.N1 (VDD), U2.N9 (VDD), U2.R1 (VDD), U2.R9 (VDD)
VCC_30_ANL: C20.2, P2.11, U1.T19 (AVCC)
VCC_33: C5.1, C17.1, C21.1, C26.1, P2.5, U1.AB19 (HPVCCIN), U1.H8 (VCC), U1.H9 (VCC), U1.H10 (VCC), U1.H15 (VCC), U1.H19 (VCC_NAND), U1.J8 (VCC), U1.J9 (VCC), U1.J10 (VCC), U1.J14 (VCC), U1.J19 (VCC_NAND), U1.L15 (UVCC_T), U1.L16 (UVCC_C), U1.N19 (VCC_CARD), U1.P16 (PLLVP25), U1.T13 (VP_HDMI), U1.W12 (VCC_LVDS), U1.W13 (VCC_LVDS), U1.W14 (VCC_LVDS), U1.W15 (VCC33_TVOUT), U1.W16 (VCC33_TVIN)

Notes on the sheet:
TODO: check this! (i2s_sck)

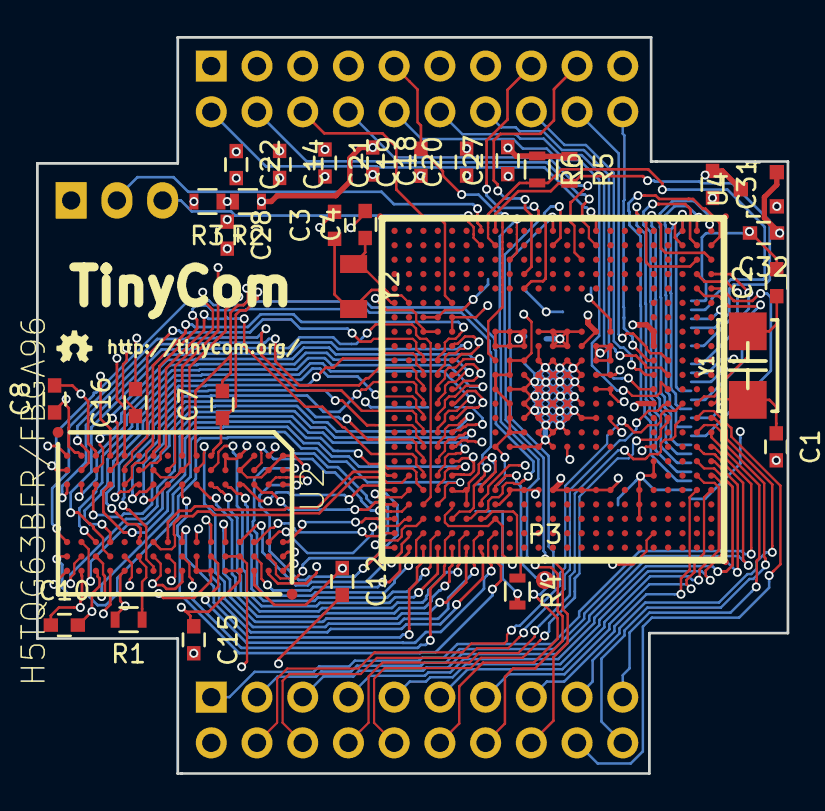
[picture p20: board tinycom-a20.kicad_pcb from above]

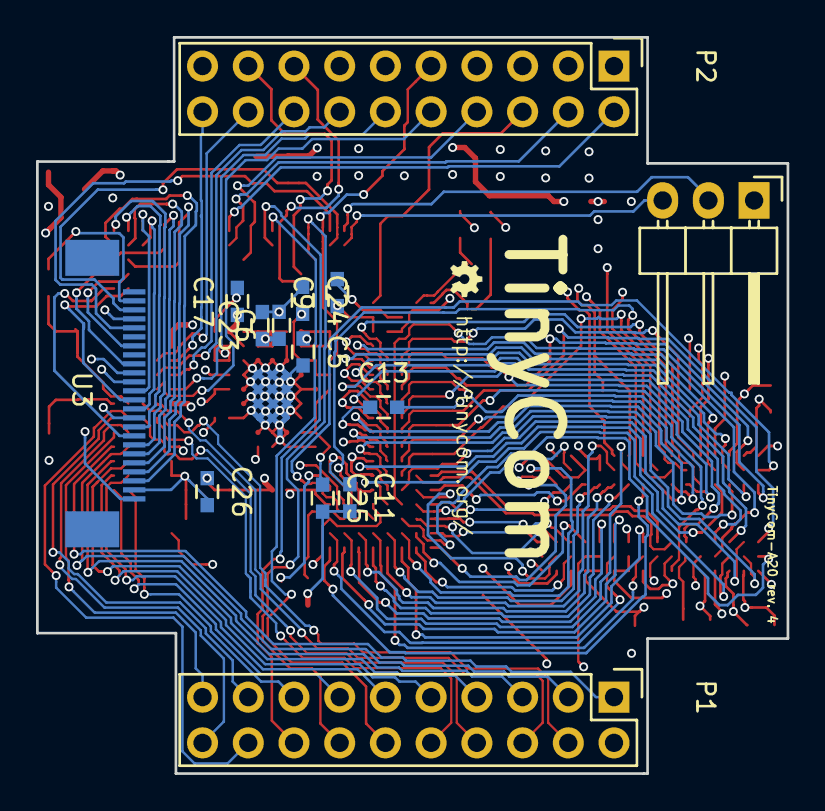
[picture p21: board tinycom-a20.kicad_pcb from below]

Board: 4 copper layers, 41.7 x 40.9 mm, 46 parts (14 on the bottom side), 113 nets.

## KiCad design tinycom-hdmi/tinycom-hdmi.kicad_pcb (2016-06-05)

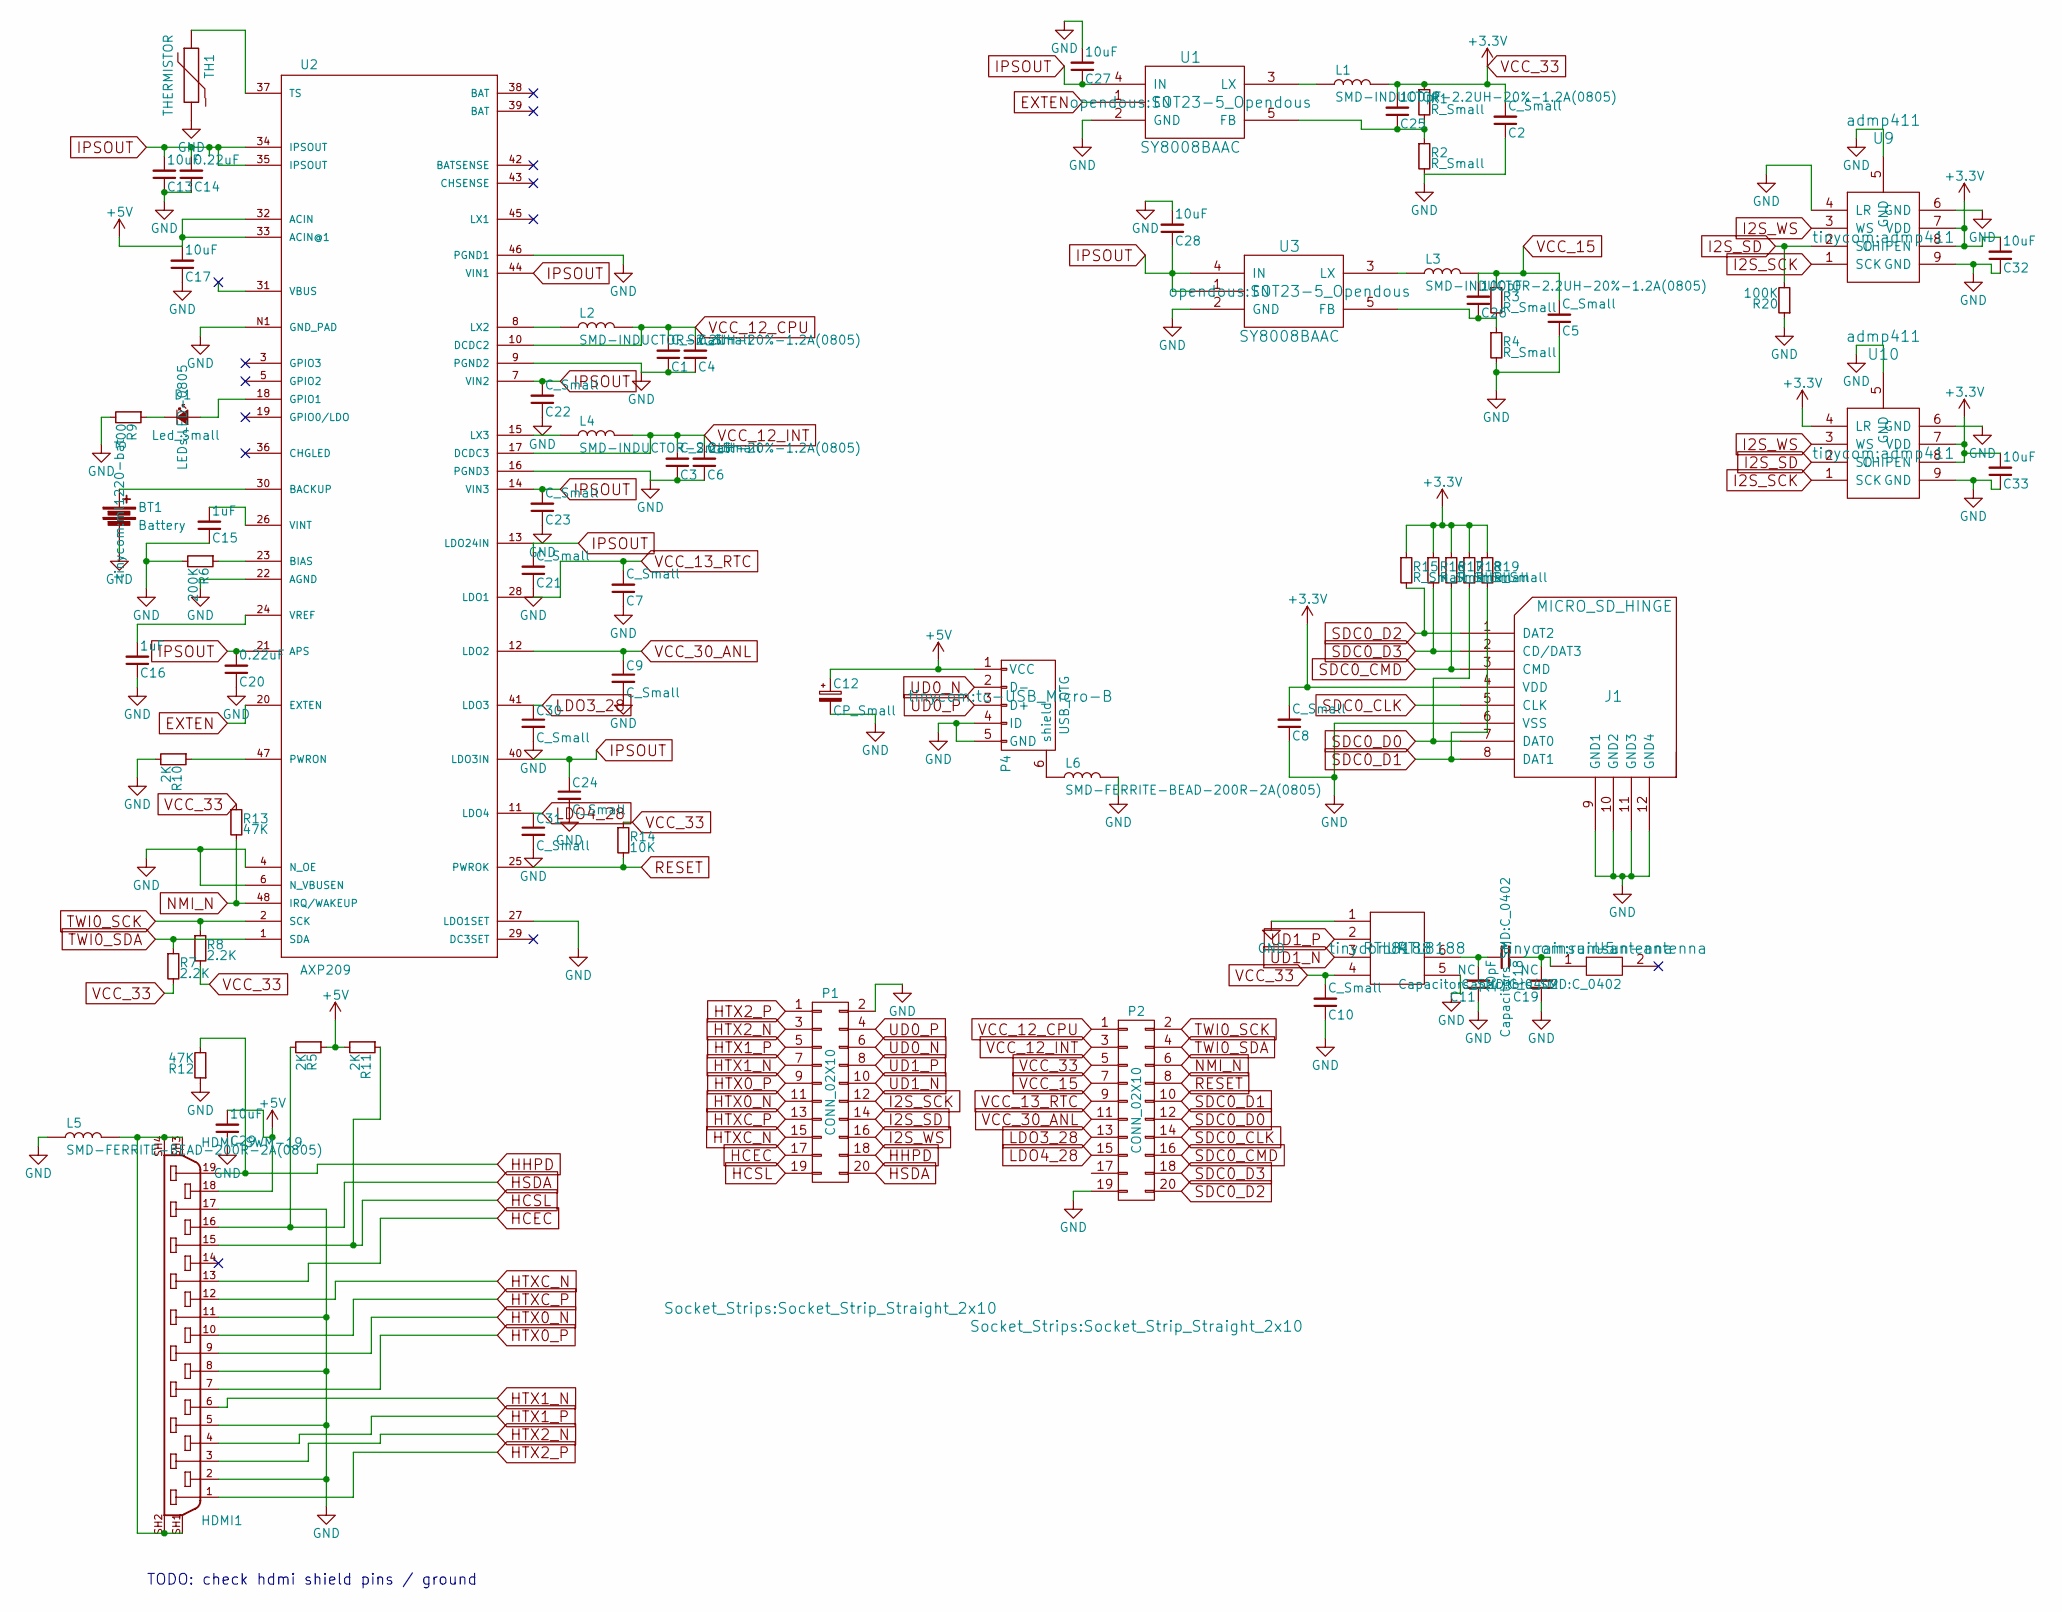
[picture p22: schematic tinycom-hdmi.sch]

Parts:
BT1: Battery; ml1220-bat
C1, C2, C3, C5, C21, C22, C23: C_Small; C_1206
C4, C6, C7, C8, C9, C10, C24, C30, C31: C_Small; C_0805
C11, C19: NC; C_0402
C12: CP_Small; TantalC_SizeA_EIA-3216_Reflow
C13, C17, C32, C33: 10uF; C_0805
C14, C20: 0.22uF; C_0805
C15, C16: 1uF; C_0805
C18: 10pF; C_0402
C25, C26: 100pF; C_1206
C27, C28, C29: 10uF; C_1206
D1: Led_Small; LED-0805
HDMI1: HDMI-SWM-19
J1: MICRO_SD_HINGE; MICRO_SD_HINGE_AMP
L1, L2, L3, L4: SMD-INDUCTOR-2.2UH-20%-1.2A(0805); CD32
L5, L6: SMD-FERRITE-BEAD-200R-2A(0805); OPL-Inductor-L0805
P1, P2: CONN_02X10; Socket_Strip_Straight_2x10
P4: USB_OTG; tc-USB_Micro-B
R1, R2, R3, R4, R15, R16, R17, R18, R19: R_Small; R_0805
R5, R10, R11: 2K; R_0805
R6: 200K; R_0805
R7, R8: 2.2K; R_0805
R9: 300; R_0805
R12, R13: 47K; R_0805
R14: 10K; R_0805
R20: 100K; R_0805
TH1: THERMISTOR; R1
U1, U3: SY8008BAAC; SOT23-5_Opendous
U2: AXP209; ax209
U4: RTL8188
U5: rainsun-antenna
U9, U10: admp411

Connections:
+5V: C12.1, C17.2, C29.2, HDMI1.18, P4.1 (VCC), R5.1, R11.2, U2.32 (ACIN), U2.33 (ACIN@1)
EXTEN: U1.1 (EN), U2.20 (EXTEN)
GND: BT1.2, C1.1, C2.1, C3.1, C4.1, C5.1, C6.1, C7.1, C8.1, C9.2, C10.1, C11.1, C12.2, C13.1, C14.1, C15.1, C16.1, C17.1, C19.1, C20.1, C21.1, C22.1, C23.1, C24.2, C27.2, C28.2, C29.1, C30.2, C31.2, C32.1, C33.1, HDMI1.2, HDMI1.5, HDMI1.8, HDMI1.11, HDMI1.17, J1.6 (VSS), J1.9 (GND1), J1.10 (GND2), J1.11 (GND3), J1.12 (GND4), L5.1, L6.2, P1.2, P2.19, P4.4 (ID), P4.5 (GND), R2.2, R4.2, R6.2, R9.2, R10.2, R12.1, R20.1, TH1.2, U1.2 (GND), U2.4 (N_OE), U2.6 (N_VBUSEN), U2.9 (PGND2), U2.16 (PGND3), U2.22 (AGND), U2.27 (LDO1SET), U2.46 (PGND1), U2.N1 (GND_PAD), U3.2 (GND), U4.1, U4.5, U9.4 (LR), U9.5 (GND), U9.6 (GND), U9.9 (GND), U10.5 (GND), U10.6 (GND), U10.9 (GND)
HCEC: HDMI1.13, P1.17
HCSL: HDMI1.15, P1.19, R11.1
HHPD: HDMI1.19, P1.18, R12.2
HSDA: HDMI1.16, P1.20, R5.2
HTX0_N: HDMI1.9, P1.11
HTX0_P: HDMI1.7, P1.9
HTX1_N: HDMI1.6, P1.7
HTX1_P: HDMI1.4, P1.5
HTX2_N: HDMI1.3, P1.3
HTX2_P: HDMI1.1, P1.1
HTXC_N: HDMI1.12, P1.15
HTXC_P: HDMI1.10, P1.13
I2S_SCK: P1.12, U9.1 (SCK), U10.1 (SCK)
I2S_SD: P1.14, R20.2, U9.2 (SD), U10.2 (SD)
I2S_WS: P1.16, U9.3 (WS), U10.3 (WS)
IPSOUT: C13.2, C14.2, C20.2, C21.2, C22.2, C23.2, C24.1, C27.1, C28.1, U1.4 (IN), U2.7 (VIN2), U2.13 (LDO24IN), U2.14 (VIN3), U2.21 (APS), U2.34 (IPSOUT), U2.35 (IPSOUT), U2.40 (LDO3IN), U2.44 (VIN1), U3.1 (EN), U3.4 (IN)
LDO3_28: C30.1, P2.13, U2.41 (LDO3)
LDO4_28: C31.1, P2.15, U2.11 (LDO4)
NMI_N: P2.6, R13.2, U2.48 (IRQ/WAKEUP)
unnamed: BT1.1, U2.30 (BACKUP)
unnamed: C11.2, C18.2, U4.6
unnamed: C15.2, U2.26 (VINT)
unnamed: C16.2, U2.24 (VREF)
unnamed: C18.1, C19.2, U5.1
unnamed: C25.1, R1.2, R2.1, U1.5 (FB)
unnamed: C26.1, R3.2, R4.1, U3.5 (FB)
unnamed: D1.1 (K), R9.1
unnamed: D1.2 (A), U2.18 (GPIO1)
unnamed: HDMI1.SH1 (20), HDMI1.SH2 (21), HDMI1.SH3 (22), HDMI1.SH4 (23), L5.2
unnamed: L1.1, U1.3 (LX)
unnamed: L2.1, U2.8 (LX2)
unnamed: L3.1, U3.3 (LX)
unnamed: L4.1, U2.15 (LX3)
unnamed: L6.1, P4.6 (shield)
unnamed: R6.1, U2.23 (BIAS)
unnamed: R10.1, U2.47 (PWRON)
unnamed: TH1.1, U2.37 (TS)
RESET: P2.8, R14.2, U2.25 (PWROK)
SDC0_CLK: J1.5 (CLK), P2.14
SDC0_CMD: J1.3 (CMD), P2.16, R17.2
SDC0_D0: J1.7 (DAT0), P2.12, R18.2
SDC0_D1: J1.8 (DAT1), P2.10, R19.2
SDC0_D2: J1.1 (DAT2), P2.20, R15.2
SDC0_D3: J1.2 (CD/DAT3), P2.18, R16.2
TWI0_SCK: P2.2, R8.1, U2.2 (SCK)
TWI0_SDA: P2.4, R7.1, U2.1 (SDA)
UD0_N: P1.6, P4.2 (D-)
UD0_P: P1.4, P4.3 (D+)
UD1_N: P1.10, U4.3
UD1_P: P1.8, U4.2
VCC_12_CPU: C1.2, C4.2, L2.2, P2.1, U2.10 (DCDC2)
VCC_12_INT: C3.2, C6.2, L4.2, P2.3, U2.17 (DCDC3)
VCC_13_RTC: C7.2, P2.9, U2.28 (LDO1)
VCC_15: C5.2, C26.2, L3.2, P2.7, R3.1
VCC_30_ANL: C9.1, P2.11, U2.12 (LDO2)
VCC_33: C2.2, C8.2, C10.2, C25.2, C32.2, C33.2, J1.4 (VDD), L1.2, P2.5, R1.1, R7.2, R8.2, R13.1, R14.1, R15.1, R16.1, R17.1, R18.1, R19.1, U4.4, U9.7 (VDD), U9.8 (CHIPEN), U10.4 (LR), U10.7 (VDD), U10.8 (CHIPEN)

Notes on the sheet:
TODO: check hdmi shield pins / ground

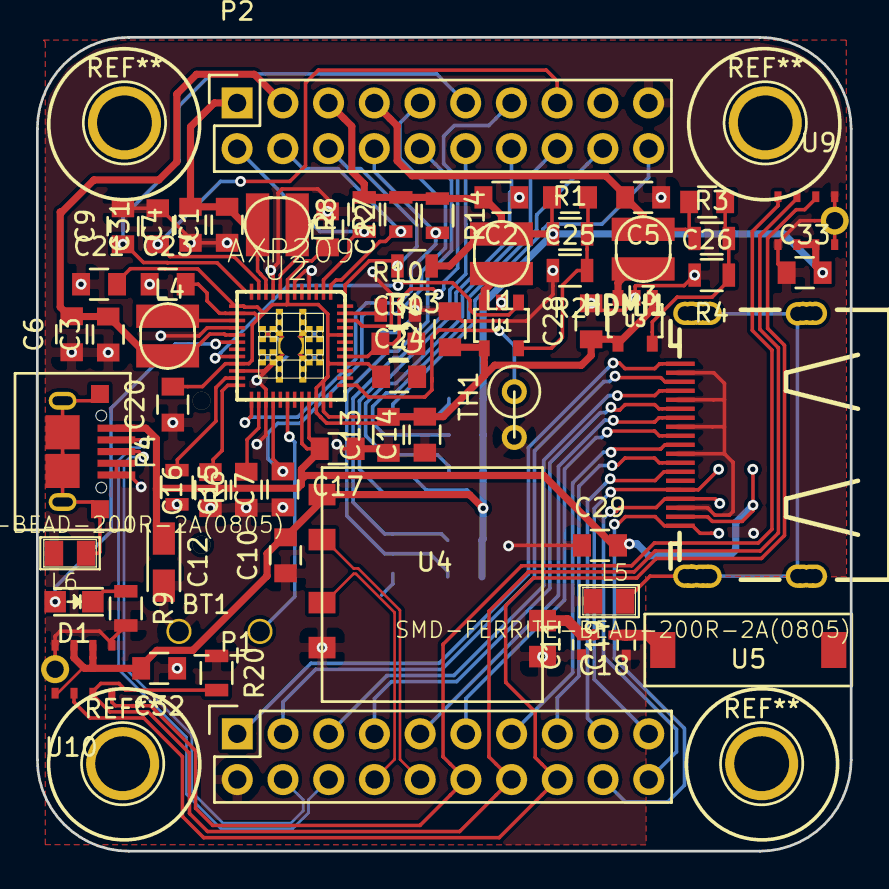
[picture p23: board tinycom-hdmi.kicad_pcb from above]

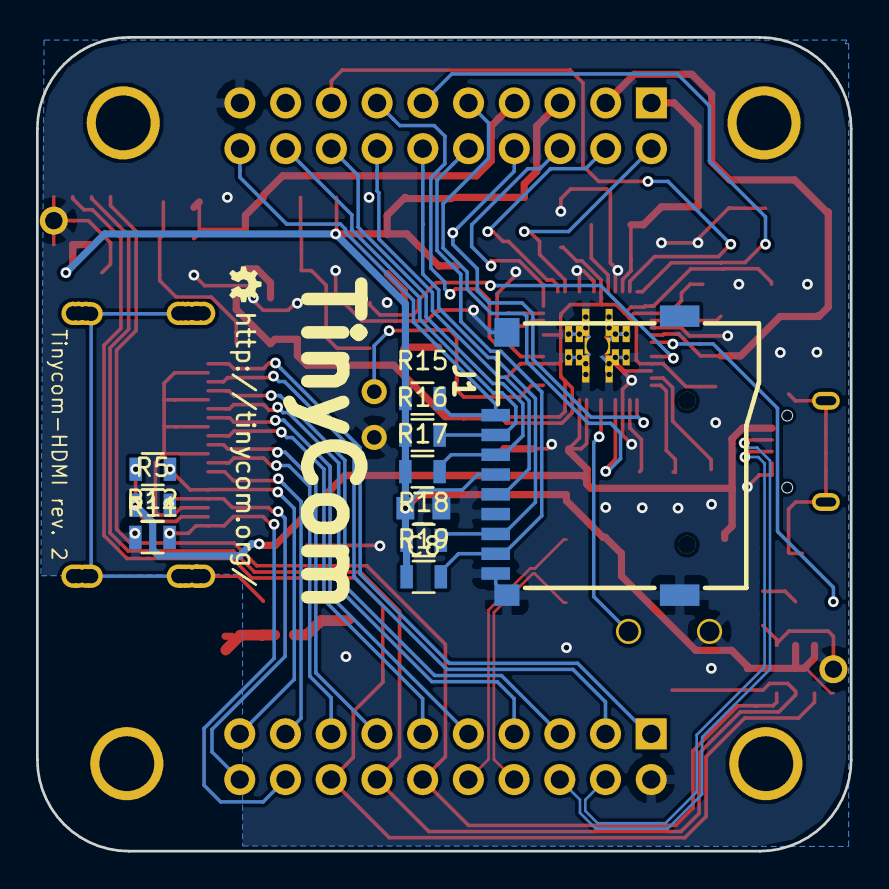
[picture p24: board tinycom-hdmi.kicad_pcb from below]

Board: 2 copper layers, 45.2 x 45.2 mm, 74 parts (10 on the bottom side), 59 nets.

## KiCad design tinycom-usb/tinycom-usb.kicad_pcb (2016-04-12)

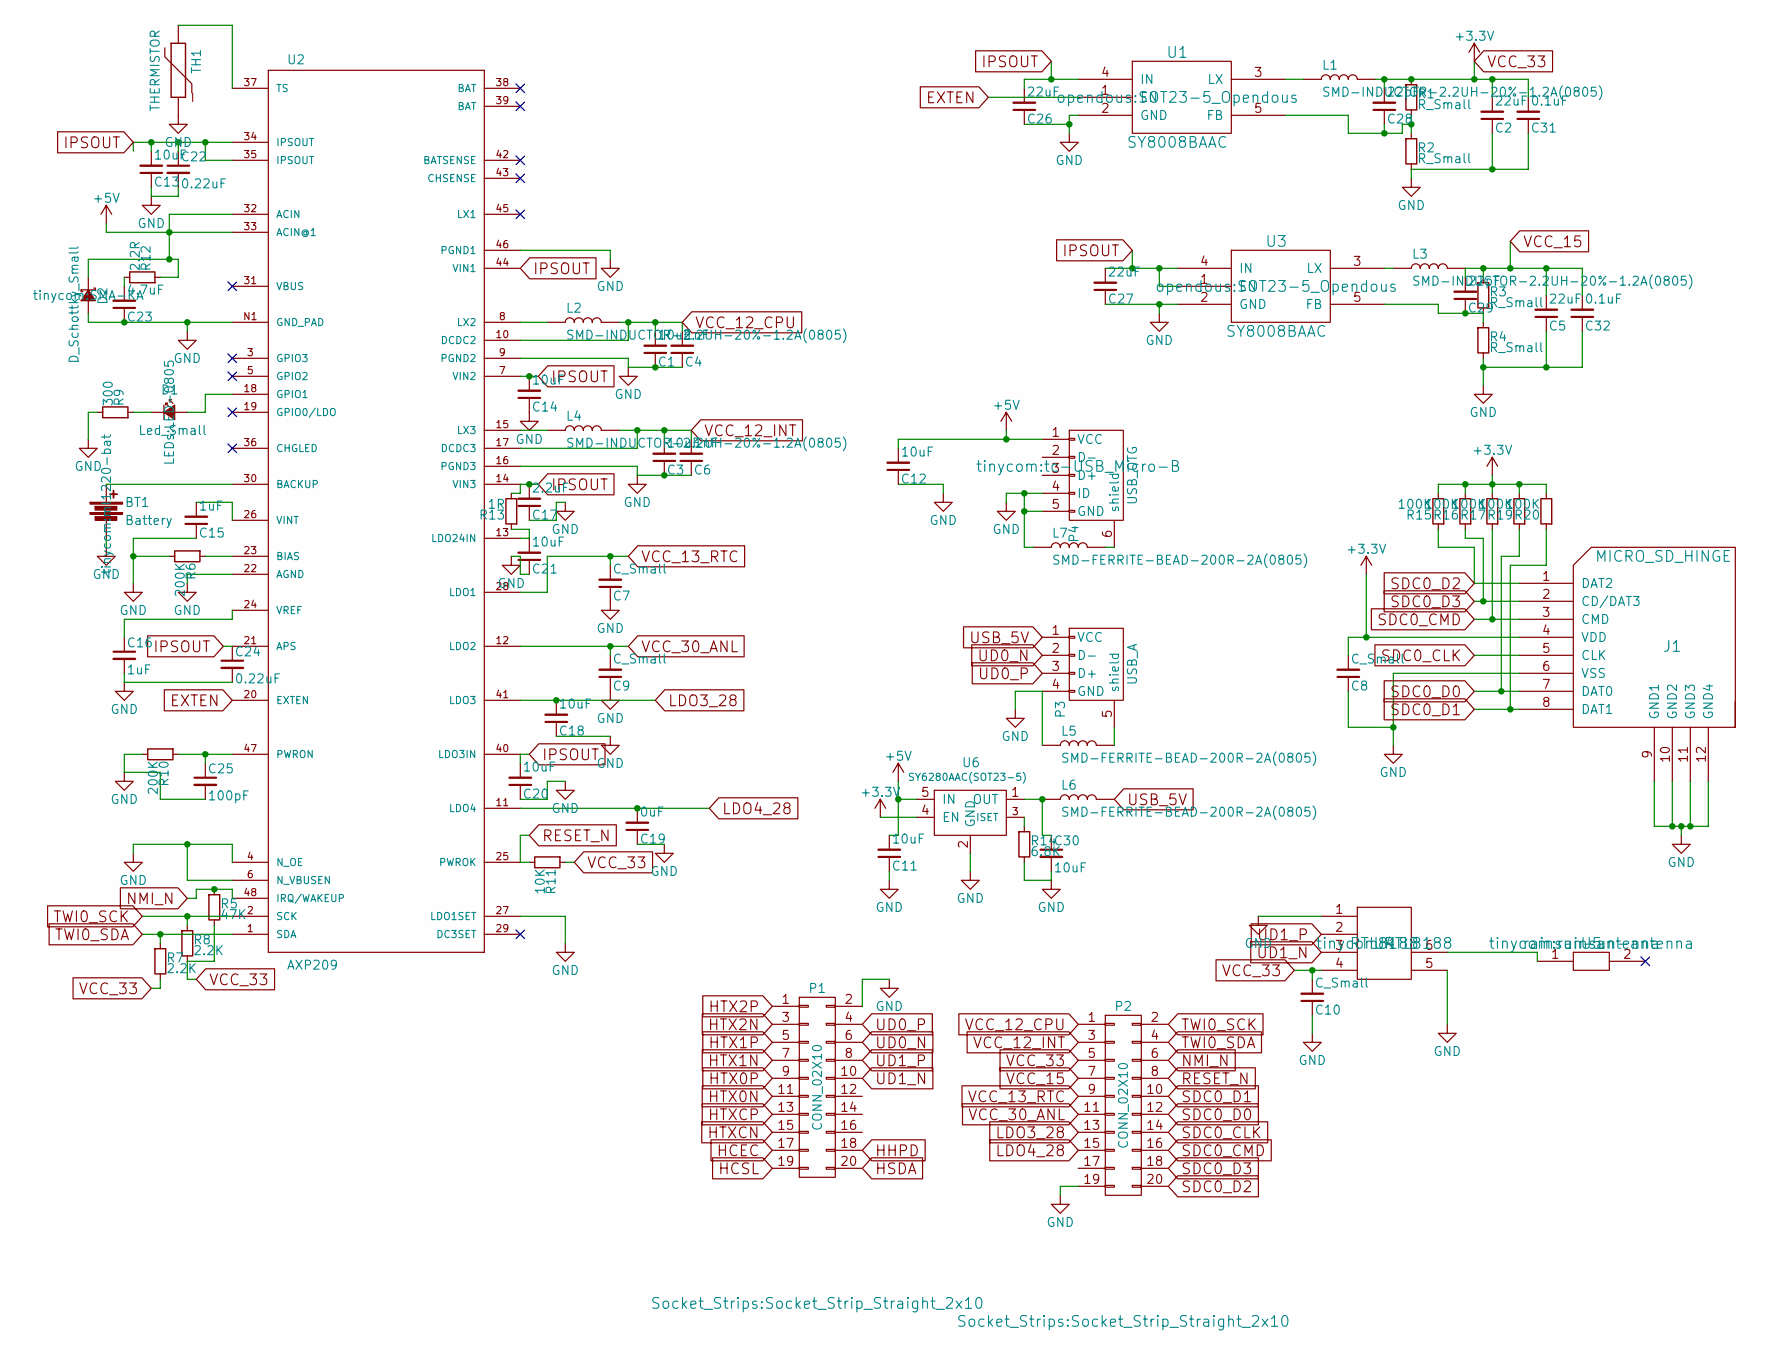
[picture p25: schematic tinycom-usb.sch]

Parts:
BT1: Battery; ml1220-bat
C1, C3: 10uF; C_1206
C2, C5, C26, C27: 22uF; C_0805
C4, C6: 1nF; C_0805
C7, C8, C9, C10: C_Small; C_0805
C11, C12, C13, C14, C18, C20, C21, C30: 10uF; C_0805
C15, C16: 1uF; C_0805
C17: 2.2uF; C_0805
C19: 0uF; C_0805
C22, C24: 0.22uF; C_0805
C23: 4.7uF; C_0805
C25: 100pF; C_0805
C28, C29: 22pF; C_0805
C31, C32: 0.1uF; C_0805
D1: Led_Small; LED-0805
D2: D_Schottky_Small; SMA-KA
J1: MICRO_SD_HINGE; MICRO_SD_HINGE_AMP
L1, L2, L3, L4: SMD-INDUCTOR-2.2UH-20%-1.2A(0805); CD32
L5, L6, L7: SMD-FERRITE-BEAD-200R-2A(0805); OPL-Inductor-L0805
P1, P2: CONN_02X10; Socket_Strip_Straight_2x10
P3: USB_A; tc-con-usb-USB-A-H
P4: USB_OTG; tc-USB_Micro-B
R1, R2, R3, R4: R_Small; R_0805
R5: 47K; R_0805
R6, R10: 200K; R_0805
R7, R8: 2.2K; R_0805
R9: 300; R_0805
R11: 10K; R_0805
R12: 2.2R; R_0805
R13: 1R; R_0805
R14: 6.8K; R_0805
R15, R16, R17, R19, R20: 100K; R_0805
TH1: THERMISTOR; R1
U1, U3: SY8008BAAC; SOT23-5_Opendous
U2: AXP209; ax209
U4: RTL8188
U5: rainsun-antenna
U6: SY6280AAC(SOT23-5); SOT23-5_Opendous

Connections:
+5V: C11.2, C12.2, D2.1 (K), P4.1 (VCC), R12.1, U2.32 (ACIN), U2.33 (ACIN@1), U6.5 (IN)
EXTEN: U1.1 (EN), U2.20 (EXTEN)
GND: BT1.2, C1.1, C2.1, C3.1, C4.1, C5.1, C6.1, C7.1, C8.1, C9.1, C10.1, C11.1, C12.1, C13.1, C14.1, C15.1, C16.2, C17.1, C18.1, C19.1, C20.1, C21.1, C22.2, C23.1, C24.2, C25.2, C26.1, C27.1, C30.2, C31.1, C32.1, D2.2 (A), J1.6 (VSS), J1.9 (GND1), J1.10 (GND2), J1.11 (GND3), J1.12 (GND4), L5.1, L7.1, P1.2, P2.19, P3.4 (GND), P4.4 (ID), P4.5 (GND), R2.2, R4.2, R6.2, R9.2, R10.2, R14.2, TH1.2, U1.2 (GND), U2.4 (N_OE), U2.6 (N_VBUSEN), U2.9 (PGND2), U2.16 (PGND3), U2.22 (AGND), U2.27 (LDO1SET), U2.46 (PGND1), U2.N1 (GND_PAD), U3.2 (GND), U4.1, U4.5, U6.2 (GND)
HCEC: P1.17
HCSL: P1.19
HHPD: P1.18
HSDA: P1.20
HTX0N: P1.11
HTX0P: P1.9
HTX1N: P1.7
HTX1P: P1.5
HTX2N: P1.3
HTX2P: P1.1
HTXCN: P1.15
HTXCP: P1.13
IPSOUT: C13.2, C14.2, C17.2, C20.2, C22.1, C24.1, C26.2, C27.2, R13.2, U1.4 (IN), U2.7 (VIN2), U2.14 (VIN3), U2.21 (APS), U2.34 (IPSOUT), U2.35 (IPSOUT), U2.40 (LDO3IN), U2.44 (VIN1), U3.1 (EN), U3.4 (IN)
LDO3_28: C18.2, P2.13, U2.41 (LDO3)
LDO4_28: C19.2, P2.15, U2.11 (LDO4)
NMI_N: P2.6, R5.1, U2.48 (IRQ/WAKEUP)
unnamed: BT1.1, U2.30 (BACKUP)
unnamed: C15.2, U2.26 (VINT)
unnamed: C16.1, U2.24 (VREF)
unnamed: C21.2, R13.1, U2.13 (LDO24IN)
unnamed: C23.2, R12.2
unnamed: C25.1, R10.1, U2.47 (PWRON)
unnamed: C28.1, R1.2, R2.1, U1.5 (FB)
unnamed: C29.1, R3.2, R4.1, U3.5 (FB)
unnamed: C30.1, L6.1, U6.1 (OUT)
unnamed: D1.1 (K), R9.1
unnamed: D1.2 (A), U2.18 (GPIO1)
unnamed: L1.1, U1.3 (LX)
unnamed: L2.1, U2.8 (LX2)
unnamed: L3.1, U3.3 (LX)
unnamed: L4.1, U2.15 (LX3)
unnamed: L5.2, P3.5 (shield)
unnamed: L7.2, P4.6 (shield)
unnamed: R6.1, U2.23 (BIAS)
unnamed: R14.1, U6.3 (ISET)
unnamed: TH1.1, U2.37 (TS)
unnamed: U4.6, U5.1
RESET_N: P2.8, R11.2, U2.25 (PWROK)
SDC0_CLK: J1.5 (CLK), P2.14
SDC0_CMD: J1.3 (CMD), P2.16, R17.1
SDC0_D0: J1.7 (DAT0), P2.12, R19.1
SDC0_D1: J1.8 (DAT1), P2.10, R20.1
SDC0_D2: J1.1 (DAT2), P2.20, R15.1
SDC0_D3: J1.2 (CD/DAT3), P2.18, R16.1
TWI0_SCK: P2.2, R8.1, U2.2 (SCK)
TWI0_SDA: P2.4, R7.1, U2.1 (SDA)
UD0_N: P1.6, P3.2 (D-)
UD0_P: P1.4, P3.3 (D+)
UD1_N: P1.10, U4.3
UD1_P: P1.8, U4.2
USB_5V: L6.2, P3.1 (VCC)
VCC_12_CPU: C1.2, C4.2, L2.2, P2.1, U2.10 (DCDC2)
VCC_12_INT: C3.2, C6.2, L4.2, P2.3, U2.17 (DCDC3)
VCC_13_RTC: C7.2, P2.9, U2.28 (LDO1)
VCC_15: C5.2, C29.2, C32.2, L3.2, P2.7, R3.1
VCC_30_ANL: C9.2, P2.11, U2.12 (LDO2)
VCC_33: C2.2, C8.2, C10.2, C28.2, C31.2, J1.4 (VDD), L1.2, P2.5, R1.1, R5.2, R7.2, R8.2, R11.1, R15.2, R16.2, R17.2, R19.2, R20.2, U4.4, U6.4 (EN)

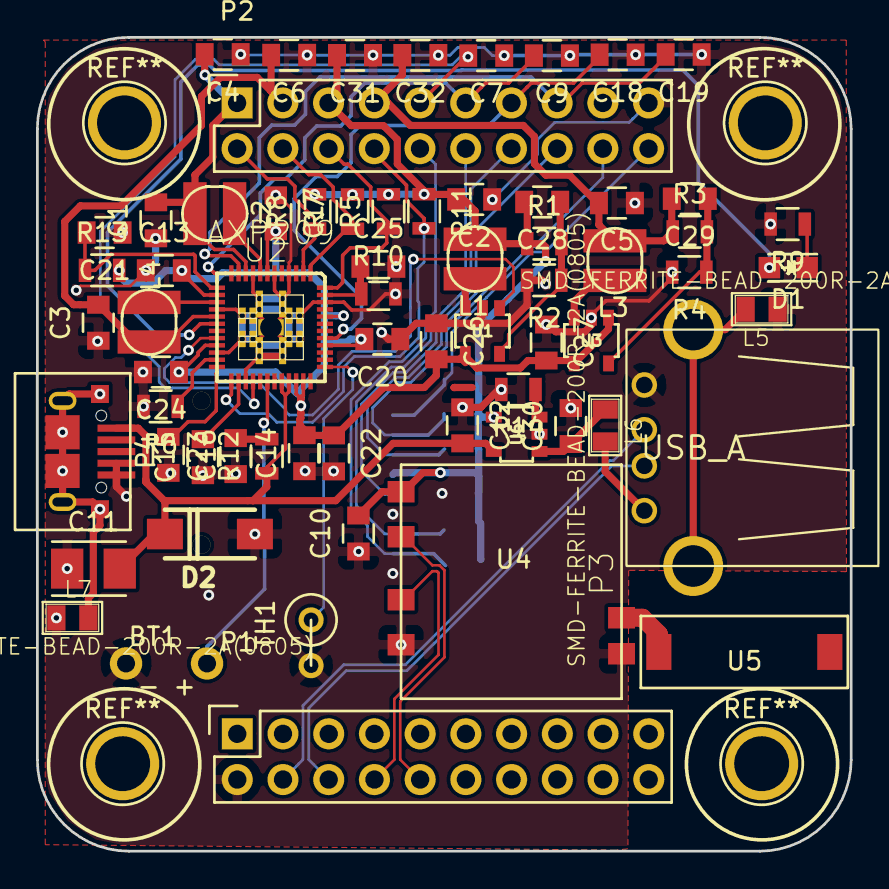
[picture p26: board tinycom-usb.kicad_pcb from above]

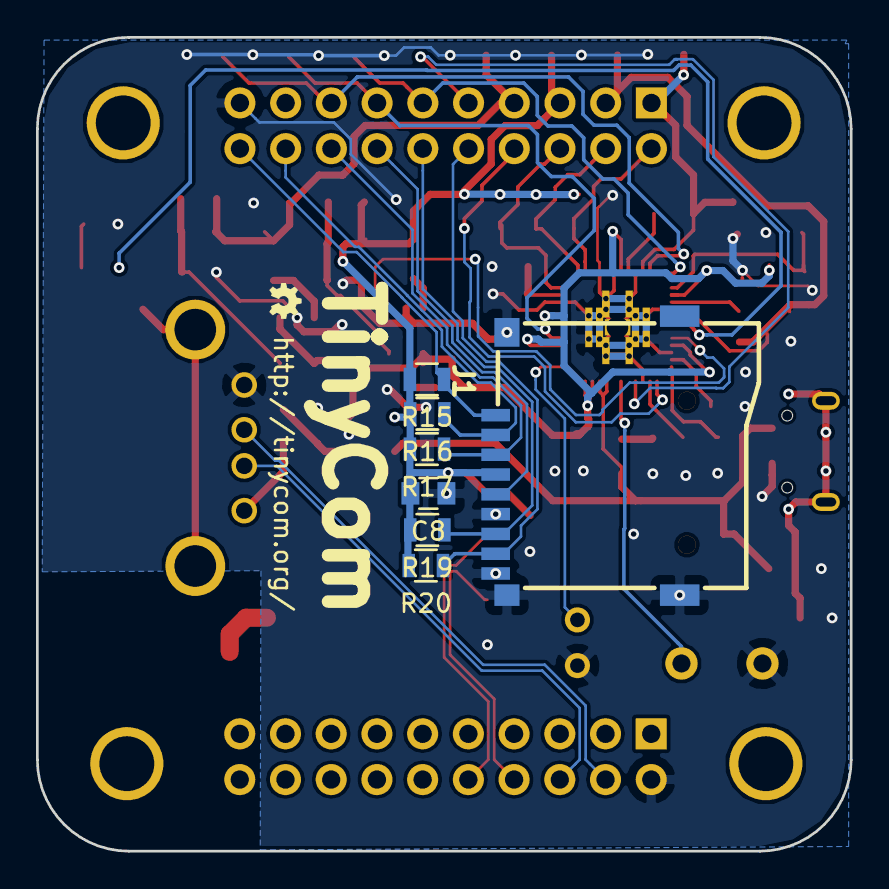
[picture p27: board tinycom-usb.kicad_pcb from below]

Board: 2 copper layers, 45.2 x 45.2 mm, 73 parts (7 on the bottom side), 48 nets.

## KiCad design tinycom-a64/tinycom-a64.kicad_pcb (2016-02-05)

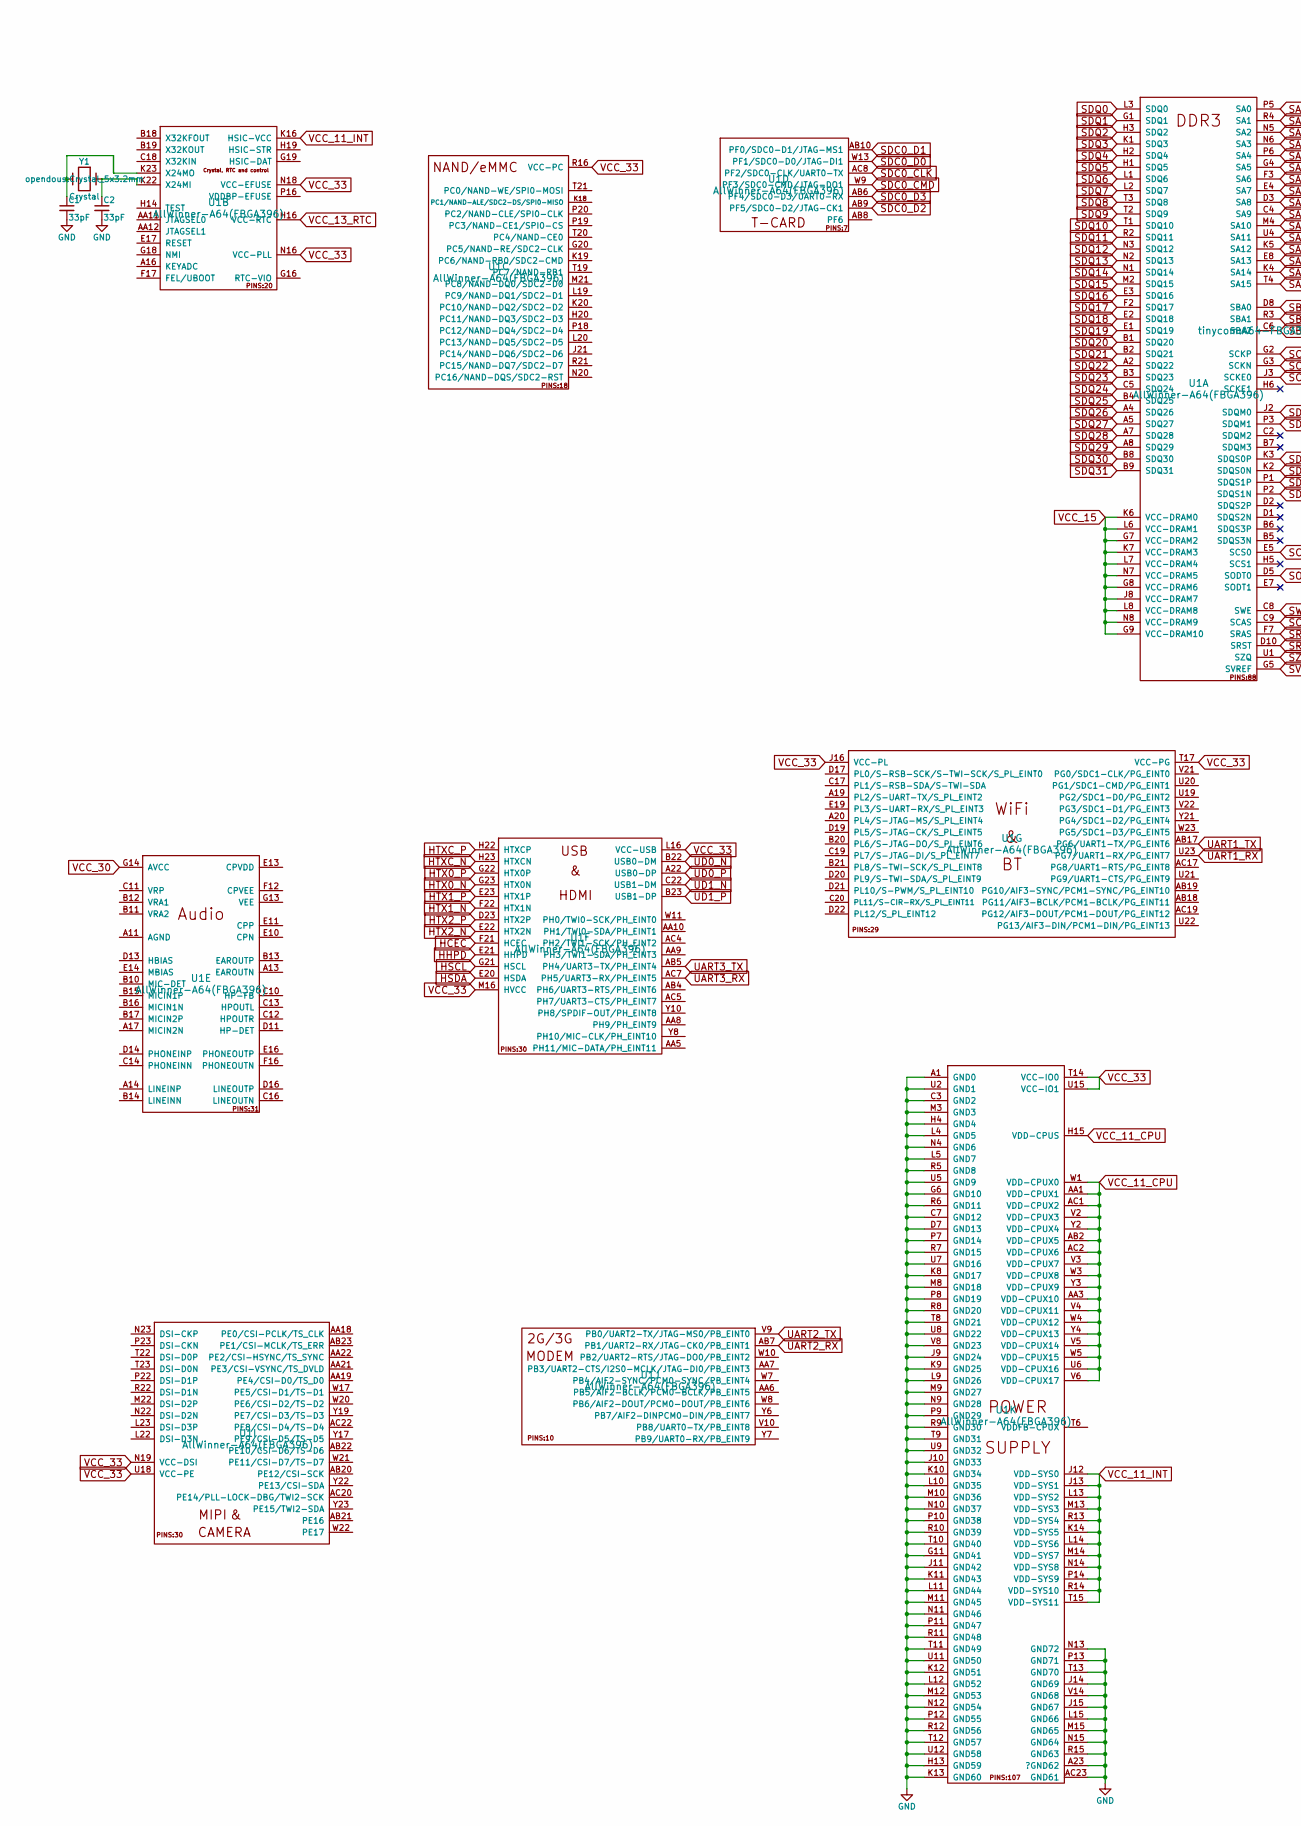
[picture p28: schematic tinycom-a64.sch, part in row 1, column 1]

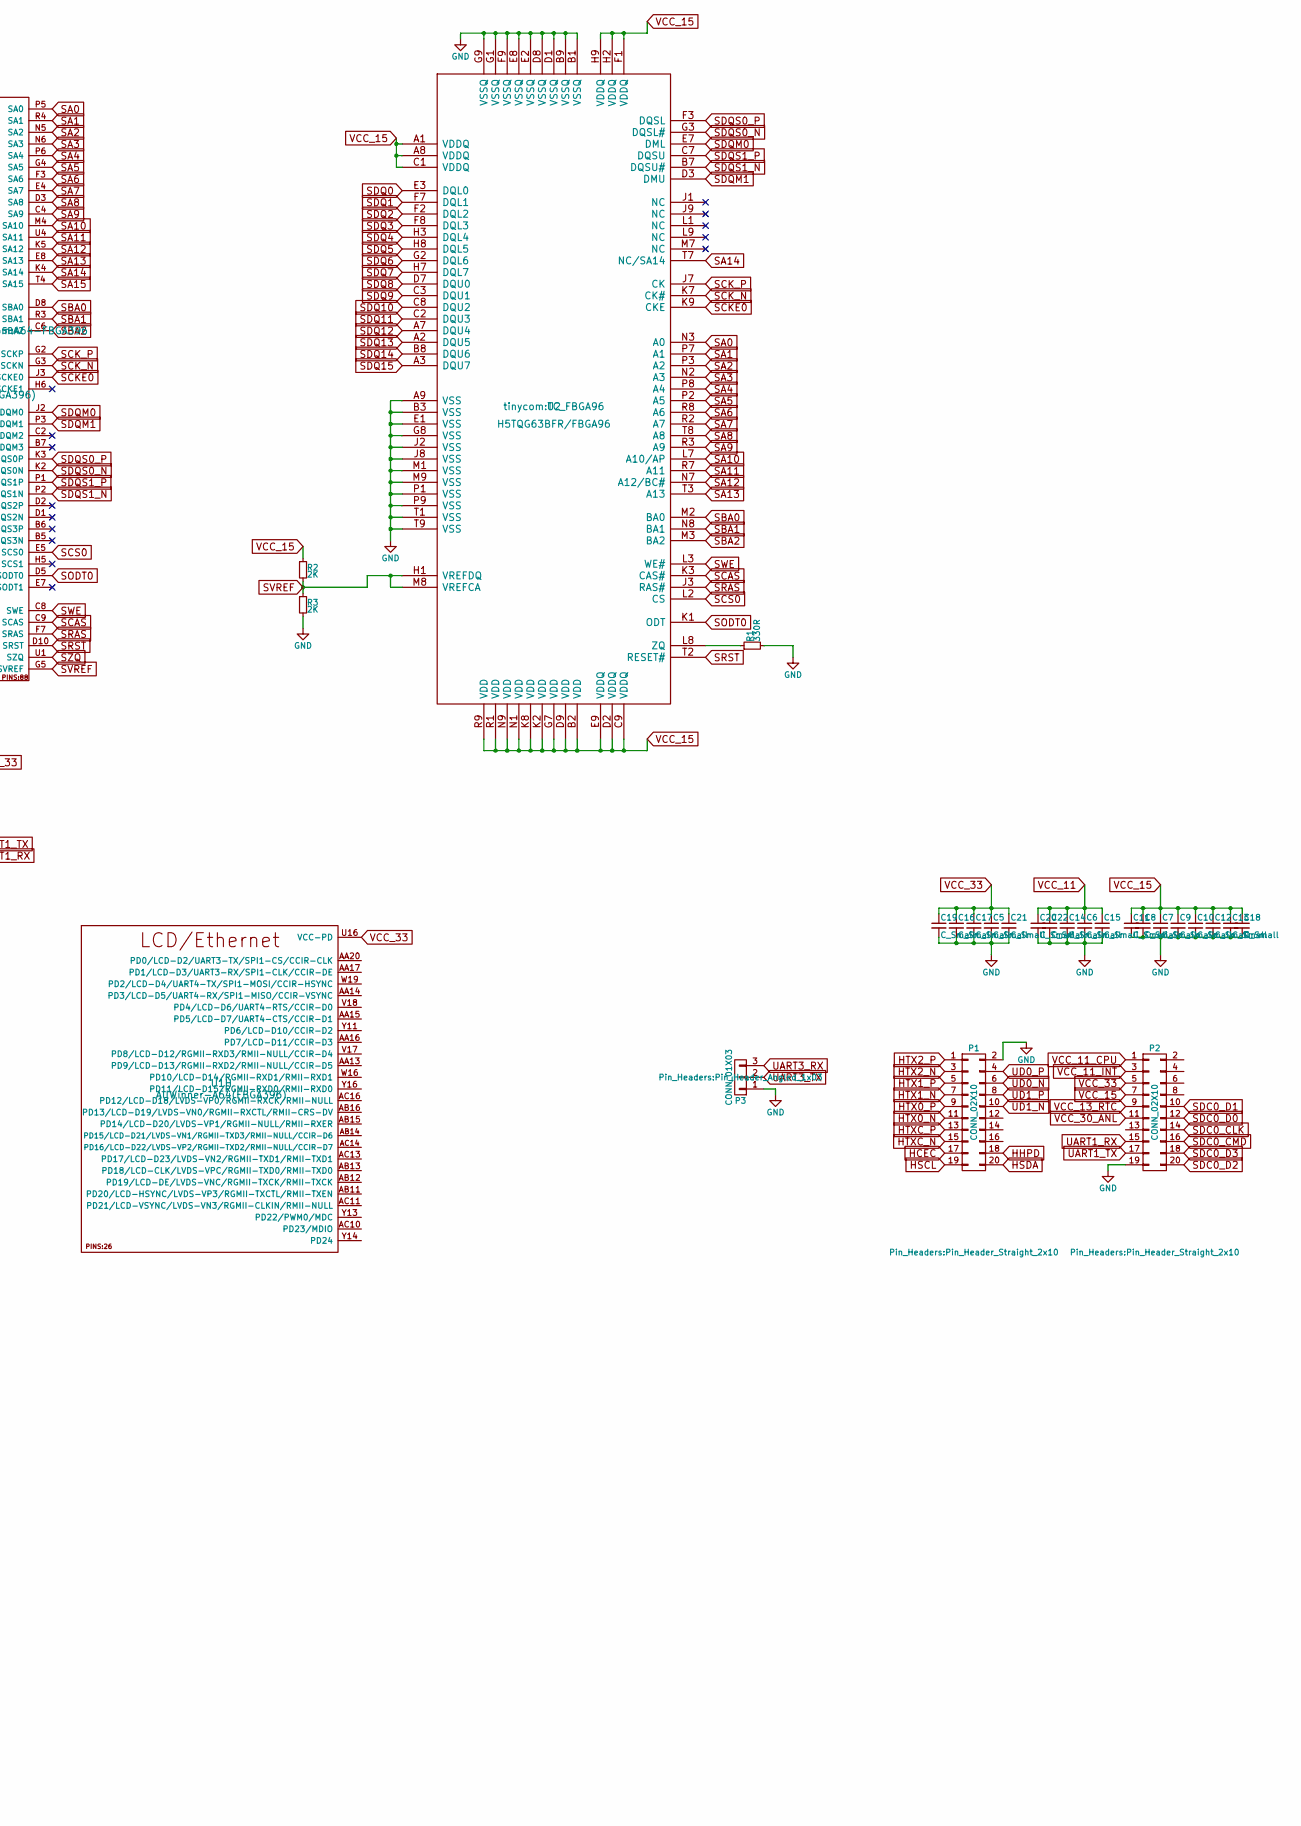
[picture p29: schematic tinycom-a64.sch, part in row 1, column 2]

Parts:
C1, C2: 33pF; C_0603
C5, C6, C7, C8, C9, C10, C11, C12, C13, C14, C15, C16, C17, C18, C19, C20, C21, C22: C_Small; C_0603
P1, P2: CONN_02X10; Pin_Header_Straight_2x10
P3: CONN_01X03; Pin_Header_Angled_1x03
R1: 330R; R_0603
R2, R3: 2K; R_0603
U1: AllWinner-A64(FBGA396); A64-FBGA396
U2: H5TQG63BFR/FBGA96; TC_FBGA96
Y1: Crystal; Crystal_5x3.2mm

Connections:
GND: C1.2, C2.2, C5.2, C6.2, C7.2, C8.2, C9.2, C10.2, C11.2, C12.2, C13.2, C14.2, C15.2, C16.2, C17.2, C18.2, C19.2, C20.2, C21.2, C22.2, P1.2, P2.19, P3.1, R1.2, R3.2, U1.A1 (GND0), U1.A23 (?GND62), U1.AC23 (GND61), U1.C3 (GND2), U1.C7 (GND12), U1.D7 (GND13), U1.G6 (GND10), U1.G11 (GND41), U1.H4 (GND4), U1.H13 (GND59), U1.J9 (GND24), U1.J10 (GND33), U1.J11 (GND42), U1.J14 (GND69), U1.J15 (GND67), U1.K8 (GND17), U1.K9 (GND25), U1.K10 (GND34), U1.K11 (GND43), U1.K12 (GND51), U1.K13 (GND60), U1.L4 (GND5), U1.L5 (GND7), U1.L9 (GND26), U1.L10 (GND35), U1.L11 (GND44), U1.L12 (GND52), U1.L15 (GND66), U1.M3 (GND3), U1.M8 (GND18), U1.M9 (GND27), U1.M10 (GND36), U1.M11 (GND45), U1.M12 (GND53), U1.M15 (GND65), U1.N4 (GND6), U1.N9 (GND28), U1.N10 (GND37), U1.N11 (GND46), U1.N12 (GND54), U1.N13 (GND72), U1.N15 (GND64), U1.P7 (GND14), U1.P8 (GND19), U1.P9 (GND29), U1.P10 (GND38), U1.P11 (GND47), U1.P12 (GND55), U1.P13 (GND71), U1.R5 (GND8), U1.R6 (GND11), U1.R7 (GND15), U1.R8 (GND20), U1.R9 (GND30), U1.R10 (GND39), U1.R11 (GND48), U1.R12 (GND56), U1.R15 (GND63), U1.T8 (GND21), U1.T9 (GND31), U1.T10 (GND40), U1.T11 (GND49), U1.T12 (GND57), U1.T13 (GND70), U1.U2 (GND1), U1.U5 (GND9), U1.U7 (GND16), U1.U8 (GND22), U1.U9 (GND32), U1.U11 (GND50), U1.U12 (GND58), U1.V8 (GND23), U1.V14 (GND68), U2.A9 (VSS), U2.B1 (VSSQ), U2.B3 (VSS), U2.B9 (VSSQ), U2.D1 (VSSQ), U2.D8 (VSSQ), U2.E1 (VSS), U2.E2 (VSSQ), U2.E8 (VSSQ), U2.F9 (VSSQ), U2.G1 (VSSQ), U2.G8 (VSS), U2.G9 (VSSQ), U2.J2 (VSS), U2.J8 (VSS), U2.M1 (VSS), U2.M9 (VSS), U2.P1 (VSS), U2.P9 (VSS), U2.T1 (VSS), U2.T9 (VSS)
HCEC: P1.17, U1.F21 (HCEC)
HHPD: P1.18, U1.E21 (HHPD)
HSCL: P1.19, U1.G21 (HSCL)
HSDA: P1.20, U1.E20 (HSDA)
HTX0_N: P1.11, U1.G23 (HTX0N)
HTX0_P: P1.9, U1.G22 (HTX0P)
HTX1_N: P1.7, U1.F22 (HTX1N)
HTX1_P: P1.5, U1.E23 (HTX1P)
HTX2_N: P1.3, U1.E22 (HTX2N)
HTX2_P: P1.1, U1.D23 (HTX2P)
HTXC_N: P1.15, U1.H23 (HTXCN)
HTXC_P: P1.13, U1.H22 (HTXCP)
unnamed: C1.1, U1.K23 (X24MO), Y1.2
unnamed: C2.1, U1.K22 (X24MI), Y1.1
unnamed: R1.1, U2.L8 (ZQ)
SA0: U1.P5 (SA0), U2.N3 (A0)
SA1: U1.R4 (SA1), U2.P7 (A1)
SA2: U1.N5 (SA2), U2.P3 (A2)
SA3: U1.N6 (SA3), U2.N2 (A3)
SA4: U1.P6 (SA4), U2.P8 (A4)
SA5: U1.G4 (SA5), U2.P2 (A5)
SA6: U1.F3 (SA6), U2.R8 (A6)
SA7: U1.E4 (SA7), U2.R2 (A7)
SA8: U1.D3 (SA8), U2.T8 (A8)
SA9: U1.C4 (SA9), U2.R3 (A9)
SA10: U1.M4 (SA10), U2.L7 (A10/AP)
SA11: U1.U4 (SA11), U2.R7 (A11)
SA12: U1.K5 (SA12), U2.N7 (A12/BC#)
SA13: U1.E8 (SA13), U2.T3 (A13)
SA14: U1.K4 (SA14), U2.T7 (NC/SA14)
SA15: U1.T4 (SA15)
SBA0: U1.D8 (SBA0), U2.M2 (BA0)
SBA1: U1.R3 (SBA1), U2.N8 (BA1)
SBA2: U1.C6 (SBA2), U2.M3 (BA2)
SCAS: U1.C9 (SCAS), U2.K3 (CAS#)
SCKE0: U1.J3 (SCKE0), U2.K9 (CKE)
SCK_N: U1.G3 (SCKN), U2.K7 (CK#)
SCK_P: U1.G2 (SCKP), U2.J7 (CK)
SCS0: U1.E5 (SCS0), U2.L2 (CS)
SDC0_CLK: P2.14, U1.AC8 (PF2/SDC0-CLK/UART0-TX)
SDC0_CMD: P2.16, U1.W9 (PF3/SDC0-CMD/JTAG-DO1)
SDC0_D0: P2.12, U1.W13 (PF1/SDC0-D0/JTAG-DI1)
SDC0_D1: P2.10, U1.AB10 (PF0/SDC0-D1/JTAG-MS1)
SDC0_D2: P2.20, U1.AB9 (PF5/SDC0-D2/JTAG-CK1)
SDC0_D3: P2.18, U1.AB6 (PF4/SDC0-D3/UART0-RX)
SDQ0: U1.L3 (SDQ0), U2.E3 (DQL0)
SDQ1: U1.G1 (SDQ1), U2.F7 (DQL1)
SDQ2: U1.H3 (SDQ2), U2.F2 (DQL2)
SDQ3: U1.K1 (SDQ3), U2.F8 (DQL3)
SDQ4: U1.H2 (SDQ4), U2.H3 (DQL4)
SDQ5: U1.H1 (SDQ5), U2.H8 (DQL5)
SDQ6: U1.L1 (SDQ6), U2.G2 (DQL6)
SDQ7: U1.L2 (SDQ7), U2.H7 (DQL7)
SDQ8: U1.T3 (SDQ8), U2.D7 (DQU0)
SDQ9: U1.T2 (SDQ9), U2.C3 (DQU1)
SDQ10: U1.T1 (SDQ10), U2.C8 (DQU2)
SDQ11: U1.R2 (SDQ11), U2.C2 (DQU3)
SDQ12: U1.N3 (SDQ12), U2.A7 (DQU4)
SDQ13: U1.N2 (SDQ13), U2.A2 (DQU5)
SDQ14: U1.N1 (SDQ14), U2.B8 (DQU6)
SDQ15: U1.M2 (SDQ15), U2.A3 (DQU7)
SDQ16: U1.E3 (SDQ16)
SDQ17: U1.F2 (SDQ17)
SDQ18: U1.E2 (SDQ18)
SDQ19: U1.E1 (SDQ19)
SDQ20: U1.B1 (SDQ20)
SDQ21: U1.B2 (SDQ21)
SDQ22: U1.A2 (SDQ22)
SDQ23: U1.B3 (SDQ23)
SDQ24: U1.C5 (SDQ24)
SDQ25: U1.B4 (SDQ25)
SDQ26: U1.A4 (SDQ26)
SDQ27: U1.A5 (SDQ27)
SDQ28: U1.A7 (SDQ28)
SDQ29: U1.A8 (SDQ29)
SDQ30: U1.B8 (SDQ30)
SDQ31: U1.B9 (SDQ31)
SDQM0: U1.J2 (SDQM0), U2.E7 (DML)
SDQM1: U1.P3 (SDQM1), U2.D3 (DMU)
SDQS0_N: U1.K2 (SDQS0N), U2.G3 (DQSL#)
SDQS0_P: U1.K3 (SDQS0P), U2.F3 (DQSL)
SDQS1_N: U1.P2 (SDQS1N), U2.B7 (DQSU#)
SDQS1_P: U1.P1 (SDQS1P), U2.C7 (DQSU)
SODT0: U1.D5 (SODT0), U2.K1 (ODT)
SRAS: U1.F7 (SRAS), U2.J3 (RAS#)
SRST: U1.D10 (SRST), U2.T2 (RESET#)
SVREF: R2.2, R3.1, U1.G5 (SVREF), U2.H1 (VREFDQ), U2.M8 (VREFCA)
SWE: U1.C8 (SWE), U2.L3 (WE#)
SZQ: U1.U1 (SZQ)
UART1_RX: P2.15, U1.U23 (PG7/UART1-RX/PG_EINT7)
UART1_TX: P2.17, U1.AB17 (PG6/UART1-TX/PG_EINT6)
UART2_RX: U1.AB7 (PB1/UART2-RX/JTAG-CK0/PB_EINT1)
UART2_TX: U1.V9 (PB0/UART2-TX/JTAG-MS0/PB_EINT0)
UART3_RX: P3.3, U1.AC7 (PH5/UART3-RX/PH_EINT5)
UART3_TX: P3.2, U1.AB5 (PH4/UART3-TX/PH_EINT4)
UD0_N: P1.6, U1.B22 (USB0-DM)
UD0_P: P1.4, U1.A22 (USB0-DP)
UD1_N: P1.10, U1.C22 (USB1-DM)
UD1_P: P1.8, U1.B23 (USB1-DP)
VCC_11: C6.1, C14.1, C15.1, C20.1, C22.1
VCC_11_CPU: P2.1, U1.AA1 (VDD-CPUX1), U1.AA3 (VDD-CPUX10), U1.AB2 (VDD-CPUX5), U1.AC1 (VDD-CPUX2), U1.AC2 (VDD-CPUX6), U1.H15 (VDD-CPUS), U1.U6 (VDD-CPUX16), U1.V2 (VDD-CPUX3), U1.V3 (VDD-CPUX7), U1.V4 (VDD-CPUX11), U1.V5 (VDD-CPUX14), U1.V6 (VDD-CPUX17), U1.W1 (VDD-CPUX0), U1.W3 (VDD-CPUX8), U1.W4 (VDD-CPUX12), U1.W5 (VDD-CPUX15), U1.Y2 (VDD-CPUX4), U1.Y3 (VDD-CPUX9), U1.Y4 (VDD-CPUX13)
VCC_11_INT: P2.3, U1.J12 (VDD-SYS0), U1.J13 (VDD-SYS1), U1.K14 (VDD-SYS5), U1.K16 (HSIC-VCC), U1.L13 (VDD-SYS2), U1.L14 (VDD-SYS6), U1.M13 (VDD-SYS3), U1.M14 (VDD-SYS7), U1.N14 (VDD-SYS8), U1.P14 (VDD-SYS9), U1.R13 (VDD-SYS4), U1.R14 (VDD-SYS10), U1.T15 (VDD-SYS11)
VCC_13_RTC: P2.9, U1.H16 (VCC-RTC)
VCC_15: C7.1, C8.1, C9.1, C10.1, C11.1, C12.1, C13.1, C18.1, P2.7, R2.1, U1.G7 (VCC-DRAM2), U1.G8 (VCC-DRAM6), U1.G9 (VCC-DRAM10), U1.J8 (VCC-DRAM7), U1.K6 (VCC-DRAM0), U1.K7 (VCC-DRAM3), U1.L6 (VCC-DRAM1), U1.L7 (VCC-DRAM4), U1.L8 (VCC-DRAM8), U1.N7 (VCC-DRAM5), U1.N8 (VCC-DRAM9), U2.A1 (VDDQ), U2.A8 (VDDQ), U2.B2 (VDD), U2.C1 (VDDQ), U2.C9 (VDDQ), U2.D2 (VDDQ), U2.D9 (VDD), U2.E9 (VDDQ), U2.F1 (VDDQ), U2.G7 (VDD), U2.H2 (VDDQ), U2.H9 (VDDQ), U2.K2 (VDD), U2.K8 (VDD), U2.N1 (VDD), U2.N9 (VDD), U2.R1 (VDD), U2.R9 (VDD)
VCC_30: U1.G14 (AVCC)
VCC_30_ANL: P2.11
VCC_33: C5.1, C16.1, C17.1, C19.1, C21.1, P2.5, U1.J16 (VCC-PL), U1.L16 (VCC-USB), U1.M16 (HVCC), U1.N16 (VCC-PLL), U1.N18 (VCC-EFUSE), U1.N19 (VCC-DSI), U1.R16 (VCC-PC), U1.T14 (VCC-IO0), U1.T17 (VCC-PG), U1.U15 (VCC-IO1), U1.U16 (VCC-PD), U1.U18 (VCC-PE)



Board: 4 copper layers, 41.7 x 40.9 mm, 29 parts (2 on the bottom side), 86 nets.

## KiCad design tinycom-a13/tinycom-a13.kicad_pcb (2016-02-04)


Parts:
C1, C2: 33pF; C_0603
C3, C4, C5, C6, C7, C8, C9, C10, C11, C12, C13, C14, C15: 100nF; C_0603
P1, P2: CONN_02X10; Pin_Header_Straight_2x10
P3: CONN_01X03; Pin_Header_Angled_1x03
P4: CONN_01X01
R1, R2: 1K; R_0603
R3, R4: 240R; R_0603
R5, R6: 10K; R_0603
U1: IC_A13; allwinner_a13-OLIMEX_IC_TQFP176
U2: H5TQ2G83BFR/FBGA82; BGA78
Y1: Crystal; Crystal_5x3.2mm

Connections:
DDR3_A0: U1.64 (DDR3_A0), U2.K3 (A0)
DDR3_A1: U1.52 (DDR3_A1), U2.L7 (A1)
DDR3_A2: U1.66 (DDR3_A2), U2.L3 (A2)
DDR3_A3: U1.65 (DDR3_A3), U2.K2 (A3)
DDR3_A4: U1.51 (DDR3_A4), U2.L8 (A4)
DDR3_A5: U1.67 (DDR3_A5), U2.L2 (A5)
DDR3_A6: U1.54 (DDR3_A6), U2.M8 (A6)
DDR3_A7: U1.71 (DDR3_A7), U2.M2 (A7)
DDR3_A8: U1.55 (DDR3_A8), U2.N8 (A8)
DDR3_A9: U1.69 (DDR3_A9), U2.M3 (A9)
DDR3_A10: U1.48 (DDR3_A10), U2.H7 (A10/AP)
DDR3_A11: U1.56 (DDR3_A11), U2.M7 (A11)
DDR3_A12: U1.50 (DDR3_A12), U2.K7 (A12/BC#)
DDR3_A13: U1.68 (DDR3_A13), U2.N3 (A13)
DDR3_A14: U1.57 (DDR3_A14), U2.N7 (A14)
DDR3_BA0: U1.63 (DDR3_BA0), U2.J2 (BA0)
DDR3_BA1: U1.49 (DDR3_BA1), U2.K8 (BA1)
DDR3_BA2: U1.61 (DDR3_BA2), U2.J3 (BA2)
DDR3_CAS_N: U1.59 (DDR3_CAS), U2.G3 (CAS#)
DDR3_CKE: U1.47 (DDR3_CKE), U2.G9 (CKE)
DDR3_CK_N: U1.46 (DDR3_CK_N), U2.G7 (CK#)
DDR3_CK_P: U1.45 (DDR3_CK), U2.F7 (CK)
DDR3_D0: U1.22 (DDR3_D0), U2.B3 (DQ0)
DDR3_D1: U1.40 (DDR3_D1), U2.C7 (DQ1)
DDR3_D2: U1.21 (DDR3_D2), U2.C2 (DQ2)
DDR3_D3: U1.41 (DDR3_D3), U2.C8 (DQ3)
DDR3_D4: U1.19 (DDR3_D4), U2.E3 (DQ4)
DDR3_D5: U1.44 (DDR3_D5), U2.E8 (DQ5)
DDR3_D6: U1.20 (DDR3_D6), U2.D2 (DQ6)
DDR3_D7: U1.42 (DDR3_D7), U2.E7 (DQ7)
DDR3_DM0: U1.29 (DDR3_DM0), U2.B7 (DM/TQDS)
DDR3_DM1: U1.28 (DDR3_DM1)
DDR3_DQS0_N: U1.32 (DDR3_DQS0_N), U2.D3 (DQS#)
DDR3_DQS0_P: U1.31 (DDR3_DQS0), U2.C3 (DQS)
DDR3_DQS1_N: U1.34 (DDR3_DQS1_N)
DDR3_DQS1_P: U1.33 (DDR3_DQS1)
DDR3_ODT: U1.72 (DDR3_ODT), U2.G1 (ODT)
DDR3_RAS_N: U1.58 (DDR3_RAS), U2.F3 (RAS#)
DDR3_RST: U1.70 (DDR3_RST), U2.N2 (RESET#)
DDR3_WE_N: U1.60 (DDR3_WE), U2.H3 (WE#)
GND: C1.2, C2.2, C3.2, C4.2, C5.2, C6.2, C7.2, C8.2, C9.2, C10.2, C11.2, C12.2, C13.2, C14.2, C15.2, P1.2, P2.2, P3.1, R2.2, R3.2, R4.2, U1.79 (AGND), U1.GND_ (GND), U2.A1 (VSS), U2.A8 (VSS), U2.B1 (VSS), U2.B2 (VSSQ), U2.B8 (VSSQ), U2.C9 (VSSQ), U2.D1 (VSSQ), U2.D8 (VSS), U2.D9 (VSSQ), U2.F2 (VSS), U2.F8 (VSS), U2.F9 (NC), U2.H2 (CS#), U2.J1 (VSS), U2.J9 (VSS), U2.L1 (VSS), U2.L9 (VSS), U2.N1 (VSS), U2.N9 (VSS)
NMI_N: P2.15, R6.1, U1.158 (NMI_N)
unnamed: C1.1, U1.92 (X24MIN), Y1.2
unnamed: C2.1, U1.91 (X24MOUT), Y1.1
unnamed: P4.1, U1.157 (UBOOT)
unnamed: R3.1, U2.H8 (ZQ)
unnamed: R4.1, U1.17 (DZQ)
unnamed: R5.1, U1.159 (RESET_N)
SDC0_CLK: P2.7, U1.110 (PF2/SDC0_CLK/UART0_TX)
SDC0_CMD: P2.5, U1.111 (PF3/SDC0_CMD/JTAG_TDO)
SDC0_D0: P2.9, U1.108 (PF1/SDC0_D0/JTAG_TDI)
SDC0_D1: P2.11, U1.107 (PF0/SDC0_D1/JTAG_TMS)
SDC0_D2: P2.1, U1.113 (PF5/SDC0_D2/JTAG_TCK)
SDC0_D3: P2.3, U1.112 (PF4/SDC0_D3/UART0_RX)
SVREF: R1.2, R2.1, U1.18 (SVREF), U2.E1 (VREFDQ), U2.J8 (VREFCA)
TWI0_SCK: P2.19, U1.101 (PB0/TWI0-SCK)
TWI0_SDA: P2.17, U1.102 (PB1/TWI0-SDA)
UART1_RX: P3.3, U1.151 (PG4/UART1_RX/EINT4)
UART1_TX: P3.2, U1.152 (PG3/UART1_TX/EINT3)
UART3_RX: P2.6, U1.13 (PG10/SPI1_CLK/UART3_RX/EINT10)
UART3_TX: P2.4, U1.12 (PG9/SPI1_CS0/UART3_TX/EINT9)
UD0_N: P1.6, U1.93 (UDM0)
UD0_P: P1.4, U1.94 (UDP0)
UD1_N: P1.10, U1.95 (UDM1)
UD1_P: P1.8, U1.96 (UDP1)
VCC_13_RTC: P2.12
VCC_14_CPU: C7.1, C10.1, P2.20, U1.4 (VDD1_CPU), U1.9 (VDD2_CPU), U1.11 (VDD3_CPU), U1.16 (VDD4_CPU), U1.156 (VDD5_CPU), U1.164 (VDD6_CPU), U1.169 (VDD7_CPU), U1.173 (VDD8_CPU)
VCC_14_INT: C8.1, C13.1, P2.18, U1.35 (VDD1_INT), U1.73 (VDD2_INT), U1.98 (VDD3-INT), U1.109 (VDD4_INT), U1.149 (VDD5_INT)
VCC_15: C3.1, C4.1, C5.1, C6.1, P2.14, R1.1, U1.23 (VCC1_DRAM), U1.30 (VCC2_DRAM), U1.43 (VCC3_DRAM), U1.53 (VCC4_DRAM), U1.62 (VCC5_DRAM), U2.A2 (VDD), U2.A9 (VDD), U2.B9 (VDDQ), U2.C1 (VDDQ), U2.D7 (VDD), U2.E2 (VDDQ), U2.E9 (VDDQ), U2.G2 (VDD), U2.G8 (VDD), U2.K1 (VDD), U2.K9 (VDD), U2.M1 (VDD), U2.M9 (VDD)
VCC_30_ANL: C15.1, P2.10, U1.81 (AVCC)
VCC_33: C9.1, C11.1, C12.1, C14.1, P2.16, R5.2, R6.2, U1.5 (VCC1), U1.76 (V33_HP), U1.97 (V33_USB), U1.100 (VCC2), U1.142 (VCC3), U1.163 (VCC4)

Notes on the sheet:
F9 to GND to make routing easier...

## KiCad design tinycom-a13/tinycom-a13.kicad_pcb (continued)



Board: 4 copper layers, 39.4 x 40.7 mm, 27 parts (14 on the bottom side), 66 nets.

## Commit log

2015-10-19 first commit: start cpu module
    [tinycom-cpu.kicad_pcb, tinycom-cpu.sch]
2015-10-19 add missing ddr connecitons
    [tinycom-cpu.kicad_pcb, tinycom-cpu.sch]
2015-10-19 add routes
    [tinycom-cpu.kicad_pcb, tinycom-cpu.sch]
2015-10-19 full ddr route
    [tinycom-cpu.kicad_pcb, tinycom-cpu.sch]
2015-10-19 fix ddr routing
    [tinycom-cpu.kicad_pcb, tinycom-cpu.sch]
2015-10-20 before change ddr
    [tinycom-cpu.kicad_pcb]
2015-10-20 change ddr to bga78
    [tinycom-cpu.kicad_pcb, tinycom-cpu.sch]
2015-10-20 route new ddr
    [tinycom-cpu.kicad_pcb, tinycom-cpu.sch]
2015-10-20 add ddr power plane
    [tinycom-cpu.kicad_pcb, tinycom-cpu.sch]
2015-10-20 router power
    [tinycom-cpu.kicad_pcb, tinycom-cpu.sch]
2015-10-20 add missing routes in ddr
    [tinycom-cpu.kicad_pcb, tinycom-cpu.sch]
2015-10-20 add some capacitors
    [tinycom-cpu.kicad_pcb, tinycom-cpu.sch]
2015-10-20 add more capacitors
    [tinycom-cpu.kicad_pcb, tinycom-cpu.sch]
2015-10-21 change to 0805 components
    [tinycom-cpu.kicad_pcb, tinycom-cpu.sch]
2015-10-21 ddr 4mil->6mil tracks, closer to cpu
    [tinycom-cpu.kicad_pcb]
2015-10-22 change other routes to 6mil
    [tinycom-cpu.kicad_pcb]
2015-10-23 add power planes
    [tinycom-cpu.kicad_pcb, tinycom-cpu.sch]
2015-10-23 fix drc
    [tinycom-cpu.kicad_pcb]
2015-10-23 svref fix
    [tinycom-cpu.kicad_pcb, tinycom-cpu.sch]
2015-10-25 add base
    [tinycom-base.kicad_pcb, tinycom-base.sch, tinycom-cpu.kicad_pcb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]
2015-10-25 add tinycom-drone
    [tinycom-drone.kicad_pcb, tinycom-drone.sch]
2015-10-31 prepare base
    [tinycom-a13.kicad_pcb, tinycom-base.kicad_pcb, tinycom-base.sch]
2015-10-31 adjust base
    [tinycom-base.kicad_pcb, tinycom-base.sch]
2015-11-07 ddr data routing
    [tinycom-a20.dsn, tinycom-a20.kicad_pcb, tinycom-a20.sch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]
2015-11-08 place ground/power ddr
    [tinycom-a20.dsn, tinycom-a20.kicad_pcb, tinycom-a20.sch]
2015-11-08 fix power
    [tinycom-a20.dsn, tinycom-a20.kicad_pcb, tinycom-a20.sch]
2015-11-08 ddr3 routing
    [_saved_tinycom-a20.sch, tinycom-a20.dsn, tinycom-a20.kicad_pcb]
2015-11-08 before change track width
    [_saved_tinycom-a20.sch, tinycom-a20.dsn, tinycom-a20.kicad_pcb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]
2015-11-08 add nand routes
    [tinycom-a20.dsn, tinycom-a20.kicad_pcb]
2015-11-09 hardware license
    [tinycom-a20.kicad_pcb, tinycom-a20.sch]
2015-11-09 a20 schematics
    [tinycom-a20.kicad_pcb, tinycom-a20.sch]
2015-11-11 add capacitors
    [tinycom-a20.kicad_pcb, tinycom-a20.sch]
2015-11-11 add routing
    [tinycom-a20.kicad_pcb, tinycom-a20.sch]
2015-11-11 before autoroute
    [tinycom-a20.kicad_pcb]
2015-11-12 add 2nd ddr
    [tinycom-a20.dsn, tinycom-a20.kicad_pcb, tinycom-a20.sch]
2015-11-12 change track/via size settings, update ddr footprints
    [tinycom-a20.dsn, tinycom-a20.kicad_pcb, tinycom-a20.sch]
2015-11-12 no tracks
    [tinycom-a20.kicad_pcb]
2015-11-12 before delete 2nd ddr3
    [tinycom-a20.dsn, tinycom-a20.kicad_pcb]
2015-11-13 before import routes
    [tinycom-a20.dsn, tinycom-a20.kicad_pcb, tinycom-a20.sch]
2015-11-13 import route
    [tinycom-a20.kicad_pcb]
2015-11-13 add power/gnd vias
    [tinycom-a20.kicad_pcb, tinycom-a20.sch]
2015-11-14 add power routes
    [tinycom-a20.dsn, tinycom-a20.kicad_pcb, tinycom-a20.sch]
2015-11-14 before autoroute remain
    [tinycom-a20.dsn, tinycom-a20.kicad_pcb]
2015-11-20 update base board
    [tinycom-a20.kicad_pcb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]
2015-11-20 route base usb+sdcard
    [tinycom-base.dsn, tinycom-base.kicad_pcb, tinycom-base.sch]
2015-11-20 done update base board
    [tinycom-base.dsn, tinycom-base.kicad_pcb]
2015-11-21 add uboot_sel test point
    [tinycom-a20.kicad_pcb, tinycom-a20.sch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]
2015-11-21 resize ddr pads
    [tinycom-a20.kicad_pcb]
2015-11-21 a20 resize pad 0.3mm
    [tinycom-a20.kicad_pcb]
2015-11-22 fix vcc_dll
    [tinycom-a20.kicad_pcb, tinycom-a20.sch]
2015-11-22 improve clearance
    [tinycom-a20.kicad_pcb]
2015-11-23 send for production
    [tinycom-base-B_Cu.gbr, tinycom-base-B_Mask.gbr, tinycom-base-B_SilkS.gbr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]
2015-12-05 improve placement
    [tinycom-a20.kicad_pcb, tinycom-a20.sch]
2015-12-05 a20 layout
    [tinycom-a20.kicad_pcb]
2015-12-05 improve base board
    [tinycom-base-B_Cu.gbr, tinycom-base-B_Mask.gbr, tinycom-base-B_SilkS.gbr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]
2015-12-05 remove a13
    [tinycom-a13.kicad_pcb, tinycom-a13.sch]
2015-12-05 before resize vias
    [tinycom-a20.kicad_pcb, tinycom-a20.sch, tinycom-base.kicad_pcb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]
2015-12-06 before reroute ddr3
    [tinycom-a20.kicad_pcb, tinycom-a20.sch]
2015-12-06 route ddr data
    [tinycom-a20.kicad_pcb]
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2015-12-09 a64 start ddr route
    [tinycom-a64.dsn, tinycom-a64.kicad_pcb, tinycom-a64.sch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]
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2016-01-16 base/a20 fixes
    [tinycom-a20.kicad_pcb, tinycom-a20.sch, tinycom-base.kicad_pcb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]
2016-01-16 change bga pad size 0.35->0.3mm
    [tinycom-a20.kicad_pcb, tinycom-a20.sch, tinycom-base.kicad_pcb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]
2016-01-17 solder mask clearance
    [tinycom-a20.kicad_pcb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]
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2016-01-22 remove vias under AXP209
    [tinycom-base-B.Cu.gbr, tinycom-base-B.Mask.gbr, tinycom-base-B.SilkS.gbr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]
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2016-02-01 fix a13 drc
    [tinycom-a13.kicad_pcb, tinycom-a13.sch]
2016-02-02 fix a20
    [tinycom-a20.kicad_pcb, tinycom-a20.sch]
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2016-03-26 update a20+base (connect reset)
    [tinycom-a20.kicad_pcb, tinycom-a20.sch, tinycom-base.kicad_pcb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]
2016-03-26 add ground fg/bg to a20
    [tinycom-a20.kicad_pcb, tinycom-base.kicad_pcb]
2016-03-26 a20 remove bottom components
    [tinycom-a20.kicad_pcb, tinycom-base.kicad_pcb]
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2016-04-10 improve tinycom-usb (usb connector+antenna)
    [tinycom-usb.kicad_pcb, tinycom-usb.sch]
2016-04-10 fix tinycom-usb exten
    [tinycom-usb.kicad_pcb, tinycom-usb.sch]
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2016-05-02 before replace
    [tinycom-hdmi.kicad_pcb, tinycom-hdmi.sch]
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2016-05-06 start add i2s to a20
    [tinycom-a20.kicad_pcb, tinycom-a20.sch, tinycom-mic.sch]
2016-05-06 missing files
    [tinycom-audio.kicad_pcb, tinycom-audio.sch]
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2016-05-06 add mic to hdmi
    [tinycom-hdmi.kicad_pcb, tinycom-hdmi.sch]
2016-05-07 start add cam to a20
    [tinycom-a20.kicad_pcb, tinycom-a20.sch]
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2016-05-20 a20: change landing pad to 0.4
    [tinycom-a20.kicad_pcb]
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2016-05-21 a20: fix CSI routing
    [tinycom-a20.kicad_pcb, tinycom-a20.sch]
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2016-05-21 a20: add caps for camera
    [tinycom-a20.kicad_pcb, tinycom-a20.sch]
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2016-06-15 a20: fix i2s clock
    [tinycom-a20.kicad_pcb, tinycom-a20.sch]
2016-06-16 fix A20 camera
    [tinycom-a20.kicad_pcb, tinycom-a20.sch]
